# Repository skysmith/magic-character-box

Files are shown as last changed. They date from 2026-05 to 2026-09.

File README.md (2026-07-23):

# Magic Character Box

Build a magic NFC story box for kids with Raspberry Pi.

Magic Character Box is a local-first maker project where NFC-tagged toys, tokens, or figures trigger songs, stories, sound effects, and family voice messages. Put a character on top, read its NFC UID, map that UID to an audio folder, and play the matching files.

Smaller sidecar enclosure preview

The finished kid box should use:

```text
5V charger -> Raspberry Pi Zero 2 W -> MAX98357A I2S amp -> passive speaker
```

The software is intentionally testable before the hardware is finished. By default it uses a keyboard-backed mock NFC reader, so you can type `DINOSAUR`, `ROCKET`, or `DAD` and verify the app loop on a Mac/Linux machine.

## Start Here

- Quick build path: [docs/quick-build.md](docs/quick-build.md)
- Build guide: [docs/assembly.md](docs/assembly.md)
- Birthday weekend path: [docs/birthday-weekend-build.md](docs/birthday-weekend-build.md)
- Materials list: [docs/materials.md](docs/materials.md)
- Wiring and pin map: [docs/wiring.md](docs/wiring.md) and [docs/pi-zero-2w-pin-map.md](docs/pi-zero-2w-pin-map.md)
- NFC registration: [docs/rf-programming.md](docs/rf-programming.md)
- Web admin: [docs/web-admin.md](docs/web-admin.md)
- Troubleshooting: [docs/troubleshooting.md](docs/troubleshooting.md)
- v0.1 release checklist: [docs/release-checklist.md](docs/release-checklist.md)
- Known limitations: [docs/known-limitations.md](docs/known-limitations.md)
- System sounds: [docs/system-sounds.md](docs/system-sounds.md)
- Hardware profiles: [docs/hardware-profiles.md](docs/hardware-profiles.md)
- Optional transactional player-load bridge: [docs/transactional-player-load.md](docs/transactional-player-load.md)
- Printable assets: [docs/printable-assets.md](docs/printable-assets.md)
- Printable STL files: [stl/](stl/README.md)
- Parametric CAD source: [cad/](cad/README.md)

## Build It Now

For the recommended first build:

1. Buy or gather the parts in [materials.md](docs/materials.md).
2. Wire the PN532 and MAX98357A from [wiring.md](docs/wiring.md).
3. Run `./scripts/install_pi.sh` on the Pi.
4. Open the dashboard at `http://<pi-hostname-or-ip>:8080`.
5. Click `Setup scan`, scan a blank sticker, name it, and add its first sound.
6. Click `Playback`, place the character on the box, and listen.

The shortest copy-and-build version is [docs/quick-build.md](docs/quick-build.md).

## Why Build This

- Screen-free, physical interaction for kids.
- Beginner-friendly Raspberry Pi, NFC, Python, and audio practice.
- Easy to personalize with a Dad Token, Grandma Token, dinosaur facts, bedtime stories, or secret missions.
- Can also become a Story Dock / Story Album: NFC-tagged printed photos that play family memories and voice notes.
- Expandable from an ugly desk demo into a kid-usable enclosure and local parent admin page.

## Story Dock Boundary

Story Dock commercial product work lives in the private sibling `story-dock`
repo. This public repo stays focused on the local Magic Character Box build and
may keep open-source bridge pieces for local photo-story and guest-recorder
flows, but not hosted backend secrets, launch plans, supplier docs, or private
customer/product strategy.

## Current Behavior

- Reads NFC UIDs from either a mock keyboard reader or a PN532 over SPI.
- Offers an explicit `pn532-ndef` hosted mode that identifies a Story Sticker
  from either a verified legacy `https://tap.getstorydock.com/s/<token>` URL or
  a versioned `https://tap.getstorydock.com/s/<T32>/SD03-0001` URL. The suffix
  path resolves its public alias through authenticated hosted config to the
  same opaque `sdpk1_...` identity. UID is only a learned local acceleration.
- Normalizes UIDs such as `04:a1:22:9b` to `04-A1-22-9B`.
- Looks up characters in `config/characters.json`.
- Stops current playback when a different known character is scanned.
- Plays the first, shuffled, or next sequenced `.mp3` file in the mapped folder.
- Ignores repeat scans of the same tag identity for a cooldown window.
- Continues playing when a tag is removed. In the MVP, only a new known tag changes playback.
- Plays a startup chime when the service starts.
- Plays a friendly discovery cue for unknown/unregistered tags.
- Shares a tiny `config/device_state.json` file with the dashboard for the last-seen tag and recent plain-language events.

Normal maker mode hot-reloads valid `characters.json` edits and preserves its
last in-memory mapping when a rewrite is invalid. Coordinated installers may
instead opt into the local, credential-free transactional player-load bridge;
it is off by default and ordinary maker installs are unchanged. See
[docs/transactional-player-load.md](docs/transactional-player-load.md).

## Quick Start: Dev Mode

```bash
cd magic-character-box
python3 -m venv .venv
. .venv/bin/activate
pip install -r requirements.txt
python -m magic_box.app --nfc mock --dry-run-audio
```

At the prompt, type:

```text
DINOSAUR
ROCKET
DAD
q
```

Dry-run audio logs what it would do without launching `mpg123`. To hear sound, add legally usable MP3 files under:

```text
audio/dinosaur/
audio/rocket/
audio/dad/
```

Then install `mpg123` and run without `--dry-run-audio`:

```bash
python -m magic_box.app --nfc mock
```

## Pi Setup

On the Raspberry Pi:

```bash
cd /home/pi/magic-character-box
./scripts/install_pi.sh
```

The install script also runs `scripts/generate_system_sounds.sh`, which creates the startup chime, unknown-tag cue, success/error cues, and silent warmup MP3.

Then enable SPI:

```bash
sudo raspi-config
```

Choose `Interface Options` -> `SPI` -> enable, then reboot.

For the MAX98357A speaker, follow `docs/wiring.md`; the Pi service files pin playback to the direct `plughw:CARD=MAX98357A,DEV=0` ALSA path so the built-in speaker behaves consistently across cards.

For a wiring cheat sheet and reserved-pin ledger, use [docs/pi-zero-2w-pin-map.md](docs/pi-zero-2w-pin-map.md). The same reservations are available as JSON in [config/pin-reservations.json](config/pin-reservations.json).

Service deployment notes are in [docs/pi-deployment.md](docs/pi-deployment.md).

## Run With Real PN532

```bash
python -m magic_box.app --nfc pn532
```

You can also use environment variables:

```bash
MAGIC_BOX_NFC=pn532 \
MAGIC_BOX_AUDIO_BACKEND=continuous-pcm \
MAGIC_BOX_AUDIO_CMD="mpg123 -q -s --rate 48000 --stereo -e s16" \
MAGIC_BOX_AUDIO_SINK_CMD="aplay -q -D plughw:CARD=MAX98357A,DEV=0 --file-type raw --format S16_LE --rate 48000 --channels 2 --buffer-time=100000 --period-time=20000" \
python -m magic_box.app
```

Ordinary `pn532` mode keeps the public maker workflow and uses the physical tag
UID. A hosted deployment can opt in to URL identity instead:

```bash
python -m magic_box.app --nfc pn532-ndef
```

In `pn532-ndef` mode, the tag must contain exactly one canonical Story Dock
NDEF HTTPS URI record. Legacy URLs are parsed completely. New suffix URLs put
the public `SDxx-xxxx` alias in a fixed page-19 read window; the player accepts
that alias only when the active hosted config maps it to a canonical
token-derived `sdpk1_...` key. A hashed local UID binding can accelerate later
taps but is never returned or configured as identity. URLs, tokens, and raw
UIDs are not written to logs or hosted config.

## Scan A Tag

```bash
python scripts/scan_tag.py --nfc pn532
```

For a laptop/dev placeholder:

```bash
python scripts/scan_tag.py --nfc mock
```

## Test Without The Reader

Before the PN532 and stickers arrive, run the real app loop with the file-backed fake reader:

```bash
MAGIC_BOX_NFC=file python -m magic_box.app --nfc file
```

In another terminal, queue pretend tag IDs:

```bash
python scripts/fake_tag.py DINOSAUR
python scripts/fake_tag.py ROCKET
python scripts/fake_tag.py DAD
```

The app consumes one queued UID at a time from `/tmp/magic-character-box-tags.txt`. This is the easiest way to test the Pi service, config lookup, cooldown behavior, and audio switching without touching NFC hardware.

The admin UI also has a `Simulate scan` button for each character. When the app service is running with `MAGIC_BOX_NFC=file`, that button queues the same fake UID and the background app plays it as if a toy had been placed on the reader.

## Register A Character

```bash
python scripts/register_character.py --nfc pn532 --name Dinosaur --mode shuffle
```

This reads one tag UID, creates a folder such as `audio/dinosaur`, and updates `config/characters.json`.
If a folder with that name already exists, the helper appends a number, such as `audio/dinosaur-2`.
Use `--folder audio/custom-name --create-folder` only when you want to override the automatic folder name.

## Device Admin UI

Run the local web admin when you want a phone/laptop interface for the box:

```bash
python -m magic_box.admin --nfc pn532 --host 0.0.0.0 --port 8080
```

Open `http://<your-pi-hostname-or-ip>:8080` on the same network.

If the Pi is on your Tailscale tailnet, Tailscale Serve can expose the same dashboard over trusted tailnet HTTPS without creating a second admin service. For example, a Tailscale URL can look like `https://your-box.your-tailnet.ts.net/`.

The admin UI can:

- Upload audio to a character immediately after files are selected.
- Upload a family voice memo from a phone or laptop.
- Record in the browser only when the page is running from a secure origin, such as localhost or a guest-only HTTPS tunnel.
- Create an upload-only guest recording link for a remote family member.
- Register an NFC tag UID without editing JSON, creating the audio folder automatically from the character name.
- Create a photo story in one pass: scan a sticker, name the memory, and generate a phone recorder link.
- Create Story Sticker URLs for the newer Story Dock flow: preassign a phone-tap link, bind the NFC UID, record from a phone, and expose the story in `/api/dock/manifest`.
- Download QR SVG fallbacks for Story Sticker links and guest recorder links. This is the free/open-source print option for people who do not have prewritten NFC URL stickers yet.
- Serve a first mobile API for future native iPhone/App Clip work at `/api/mobile/story-stickers/<token>`.
- Point Story Sticker links at a hosted/tunneled URL with `MAGIC_BOX_PUBLIC_STORY_BASE_URL` during staging.
- Switch between setup scanning and kid playback mode from the dashboard.
- Check Wi-Fi status, scan nearby networks, and connect through the local NetworkManager controls on the Pi.
- Use the last-seen tag to teach a new character without copying a UID.
- Run a one-click box test from the hidden tools drawer.
- Download a backup zip of `config/` and `audio/`.
- Shut down the Pi cleanly from the local dashboard.
- Leave room for experimental Bluetooth speaker work without making it part of the main build.
- Show guidance for custom 3D printable figures.

Browser recordings are converted to MP3 when `ffmpeg` is installed. `scripts/install_pi.sh` installs `ffmpeg` on the Pi.

For Grandma-style remote messages, create a guest recording link from the dashboard or command line:

```bash
python scripts/create_guest_link.py --name "Dad Token" --label "Grandma birthday message" --base-url https://your-temporary-tunnel.example
```

The guest page is upload-only. For a temporary public tunnel, run the app in `--guest-only` mode on a separate local port so the tunnel cannot serve the dashboard, scan controls, file deletion, Bluetooth controls, or system mode buttons. That guest recorder is not a second dashboard; the single parent dashboard stays on `http://<pi-hostname-or-ip>:8080`.

When using the real PN532 Scan button, run the real admin service and stop the mock/dev admin service. If the Scan button is disabled and the page says browser scan is unavailable, the admin is running in mock mode.

See [docs/web-admin.md](docs/web-admin.md), [docs/rf-programming.md](docs/rf-programming.md), and [docs/3d-printable-figures.md](docs/3d-printable-figures.md).

Bluetooth controls are intentionally treated as an experimental socket for future contributors. The finished kid box defaults to the wired MAX98357A amp path because it boots predictably and does not depend on a paired accessory.

## Install Services

After copying the repo to `/home/pi/magic-character-box` and running `scripts/install_pi.sh`:

```bash
sudo cp systemd/magic-character-box.service /etc/systemd/system/
sudo systemctl daemon-reload
```

To install the web admin as a separate service:

```bash
sudo cp systemd/magic-character-box-admin.service /etc/systemd/system/
sudo systemctl daemon-reload
```

The MVP app and admin page are separate PN532 readers. Use either setup mode or kid playback mode:

```bash
# Setup mode: register tags and upload/record audio
sudo systemctl disable --now magic-character-box
sudo systemctl disable --now magic-character-box-admin-dev
sudo systemctl enable --now magic-character-box-admin

# Kid playback mode
sudo systemctl disable --now magic-character-box-admin
sudo systemctl enable --now magic-character-box
```

Watch logs with `journalctl -u magic-character-box -f` or `journalctl -u magic-character-box-admin -f`.

Adjust `WorkingDirectory`, `User`, and `ExecStart` in the service file if you install somewhere other than `/home/pi/magic-character-box`.

## Tutorial Stages

Follow [docs/tutorial-roadmap.md](docs/tutorial-roadmap.md):

1. The ugly magic demo.
2. Make it kid-usable.
3. The birthday box.
4. Parent-friendly admin.

The first printable case model is in [cad/](cad/README.md). It has rounded dice-like edges, a screw top, side speaker holes, and internal spaces for the Pi, PN532 reader, MAX98357A amp, and a small passive speaker.

The smaller current prototype enclosure is the sidecar version. It mounts the electronics beside an existing passive speaker cabinet. Ready-to-slice STL files are in [stl/](stl/README.md):

- `small-sidecar-enclosure-body.stl`
- `small-sidecar-enclosure-lid.stl`
- `nfc-character-base-flat.stl`

## Open Source And Media

This repo is licensed under Apache License 2.0. See [LICENSE](LICENSE).

The repo intentionally does not include music, stories, character art, or private voice recordings. Add your own audio locally. Good sources include family recordings, original audio, public-domain media, and Creative Commons audio with compatible terms.

See [docs/open-source-notes.md](docs/open-source-notes.md), [docs/audio-sources.md](docs/audio-sources.md), and [CONTRIBUTING.md](CONTRIBUTING.md).

## Project Screenshots And Photos

Useful open-source presentation assets are included under `docs/assets/`:

- Dashboard screenshot: [docs/assets/screenshots/software-admin-library.png](docs/assets/screenshots/software-admin-library.png)
- Bluetooth/future socket screenshot: [docs/assets/screenshots/software-bluetooth-control.png](docs/assets/screenshots/software-bluetooth-control.png)
- Pi header photo: [docs/assets/photos/pi-zero-2w-header.jpg](docs/assets/photos/pi-zero-2w-header.jpg)
- Amp wiring photo: [docs/assets/photos/max98357a-wired-to-pi.jpg](docs/assets/photos/max98357a-wired-to-pi.jpg)

Before publishing new photos, use the checklist in [docs/release-checklist.md](docs/release-checklist.md).

## Notes

- NFC UIDs are fine toy identifiers, not security credentials.
- Do not connect a passive speaker directly to the Pi. The MAX98357A drives the speaker; the Pi only powers the amp and sends I2S audio.
- Keep audio local for the birthday MVP. Streaming services can wait.

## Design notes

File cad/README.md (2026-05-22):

# Case CAD

This folder contains a first printable enclosure for the Magic Character Box.

The default model is a two-piece screw-top box. That is the recommended first print because you can open the box, move the NFC reader, fix wiring, replace the speaker, and iterate without destroying the case.

There is also a `sidecar` variant for the current prototype direction: keep an existing passive speaker as the speaker cabinet and Velcro a smaller electronics module to its side or back.

## Files

- `magic-character-box-case.scad`: parametric OpenSCAD source.
- `nfc-character-base.scad`: reusable character puck with an underside NFC sticker recess.
- `build_case.sh`: renders STL files when OpenSCAD is installed.
- `build/`: generated STL output.
- `../stl/`: small public STL set for the recommended sidecar enclosure and NFC base.

## Design

- Rounded/blunted dice-like edges.
- Removable screw top.
- Side-face speaker perforations on both left and right sides.
- Raised top target ring for NFC character placement on the standalone box.
- Underside lid tray sized for a PN532 V3-style reader on the standalone box.
- Bottom standoffs for Raspberry Pi Zero 2 W.
- Small amp pad for a MAX98357A board.
- Broad front cable window for USB power/data during prototyping.

## Sidecar Variant

The sidecar variant is for mounting the Pi/NFC/amp electronics to an existing passive speaker cabinet with hook-and-loop tape.

Differences from the standalone box:

- Slightly smaller footprint and height.
- No printed speaker grille/perforations.
- Flat rear Velcro pad.
- Two rounded vertical strap slots as a backup to adhesive Velcro. They also make the rear face look intentionally character-like.
- Shallow smile and cheek details on the rear pad.
- Small side exit for speaker wires running to the speaker terminals.
- The PN532 mounts in a shallow recessed pocket under the lid instead of a printed tray. This keeps the antenna close to the NFC tag and gives clone PN532 boards extra clearance.
- The ready-to-slice sidecar lid omits the raised NFC target ring and is exported with the flat visible face on the print bed, so it can print without support material. Mark the target area later with paint, vinyl, or a sticker.

Keep the PN532/NFC target several inches away from the speaker magnet and metal hardware when choosing the exact Velcro location.

Ready-to-slice sidecar files are copied to [`../stl/`](../stl/README.md):

- `small-sidecar-enclosure-body.stl`
- `small-sidecar-enclosure-lid.stl`
- `small-sidecar-enclosure-assembly.stl` for visual/reference use

## Hardware Assumptions

- Raspberry Pi Zero 2 W: 65 mm x 30 mm board footprint.
- PN532 V3-style NFC reader: about 42.7 mm x 40.4 mm.
- MAX98357A amp breakout: mounted with tape/zip tie on the small internal amp pad.
- Speaker: small passive speaker mounted behind either perforated side face with foam tape, hot glue, or a printed bracket in a later revision.
- Sidecar Pi standoffs: raised to 8 mm so the Pi Zero 2 W USB ports line up better with the cable access window.

Measure your exact parts before a final gift print. Clone boards can vary.

## Render STLs

```bash
cd cad
./build_case.sh
```

Or render one part:

```bash
openscad -o build/magic-character-box-body.stl -D 'part="body"' magic-character-box-case.scad
openscad -o build/magic-character-box-lid.stl -D 'part="lid"' magic-character-box-case.scad
```

Render the smaller sidecar parts:

```bash
openscad -o build/magic-character-box-sidecar-body.stl -D 'variant="sidecar"' -D 'part="body"' magic-character-box-case.scad
openscad -o build/magic-character-box-sidecar-lid.stl  -D 'variant="sidecar"' -D 'part="lid"'  magic-character-box-case.scad
```

Render only the reusable NFC figure bases:

```bash
openscad -o build/nfc-character-base-flat.stl   -D 'part="flat"'   nfc-character-base.scad
openscad -o build/nfc-character-base-peg.stl    -D 'part="peg"'    nfc-character-base.scad
openscad -o build/nfc-character-base-socket.stl -D 'part="socket"' nfc-character-base.scad
```

## Reusable Character Base

The character base is a 42 mm rounded puck sized for common 25 mm NTAG213/215/216 stickers.

- `nfc-character-base-flat.stl`: default base. Merge a figure STL onto the flat top pad.
- `nfc-character-base-peg.stl`: adds a small center peg for figures designed with a matching hole.
- `nfc-character-base-socket.stl`: adds a center socket for figures designed with a matching peg.
- `nfc-character-base-demo.stl`: quick visual reference with a simple placeholder figure.

The NFC sticker goes in the underside recess. Keep the sticker on the bottom face so it sits close to the reader in the box lid. Cover it with thin felt or tape if the figure will slide around.

Base source-of-truth dimensions:

| Feature | Value |
| --- | ---: |
| Base diameter | 42 mm |
| Main base height | 8 mm |
| Flat variant total height | 8.8 mm |
| Top landing pad | 32 mm diameter x 0.8 mm high |
| Sticker recess | 26.4 mm diameter x 0.8 mm deep |
| Intended sticker | 25 mm round NTAG213/215/216 |
| Removal notch | 7 mm diameter |
| Peg variant | 7.8 mm diameter x 3.2 mm high |
| Socket variant | 8.4 mm diameter x 3.4 mm deep |

More figure workflow notes are in [`../docs/3d-printable-figures.md`](../docs/3d-printable-figures.md).

## Print Notes

Suggested first settings:

- Material: PLA or PETG.
- Layer height: 0.2 mm.
- Walls: 3.
- Top/bottom layers: 4.
- Infill: 15-20%.
- Supports: off for the sidecar body and lid. Check your slicer preview for the standalone lid lip and PN532 tray.
- Screws: start with M2.5 or small self-tapping screws. The lid uses clearance holes and the body has pilot holes.

Print the body open-side up. The sidecar lid STL is already oriented flat-side down; print it as-is with the internal lip and PN532 recess facing upward.

For the sidecar, put adhesive Velcro on the flat rear pad. If the tape alone feels weak, pass a thin Velcro strap or zip tie through the two rounded vertical eye slots. Route the speaker wire through the small side exit.

Print the NFC character base flat-side down with supports off. The underside sticker recess is shallow enough to bridge cleanly on most printers, but check the slicer preview.

For the full public build flow, see [`../docs/assembly.md`](../docs/assembly.md).

## Assembly Order

1. Print the body and lid.
2. Test fit screws before installing electronics.
3. Mount the Pi Zero 2 W on the floor standoffs.
4. Mount the MAX98357A amp on the internal amp pad.
5. For the sidecar lid, hot-glue, foam-tape, or VHB-tape the PN532 reader into the recessed pocket, antenna facing the thin lid window. For the standalone lid, mount the PN532 reader under the lid in the tray.
6. For the standalone box, mount the speaker behind a side perforation field. For the sidecar, route speaker wires out to the speaker terminals.
7. Wire everything with the Pi powered off.
8. Run NFC/audio tests before closing the lid.

## Paused-Print Variant

A mid-print component capture is possible, but it is not the recommended first version. It makes repairs and debugging much harder, and the print bed/nozzle environment is not friendly to electronics.

If you still want a captured-electronics print later, use this screw-top model as the dimensional prototype first. Once board positions are confirmed, a later model can remove the lid seam and add a slicer pause just before the top bridge closes.

## Sources For Dimensions

- Raspberry Pi Zero 2 W mechanical drawing: https://datasheets.raspberrypi.com/rpizero2/raspberry-pi-zero-2-w-mechanical-drawing.pdf
- Raspberry Pi Zero 2 W hardware docs: https://www.raspberrypi.com/documentation/hardware/raspberry-pi-zero-2/
- PN532 V3 guide dimensions commonly list the board around 42.7 mm x 40.4 mm.

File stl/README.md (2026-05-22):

# Printable STL Files

This folder contains ready-to-slice STL files for the first public build.

The OpenSCAD source lives in [`../cad/`](../cad/README.md). If you change dimensions, regenerate these files with:

```bash
./cad/build_case.sh
```

## Smaller Sidecar Enclosure

Use these when mounting the electronics module to the side or back of an existing passive speaker cabinet:

- [`small-sidecar-enclosure-body.stl`](small-sidecar-enclosure-body.stl)
- [`small-sidecar-enclosure-lid.stl`](small-sidecar-enclosure-lid.stl)
- [`small-sidecar-enclosure-assembly.stl`](small-sidecar-enclosure-assembly.stl) for visual/reference use

Print the body open-side up. The lid STL is already oriented with its flat visible face on the print bed; print it as-is with supports off.

The sidecar lid has a recessed PN532 pocket on the inside. Hot-glue, foam-tape, or VHB-tape the reader into that pocket with the antenna facing the thin lid window.

The sidecar body has rounded rear strap slots that double as a cute face, plus shallow smile and cheek details on the rear pad. The Pi standoffs are raised so the Pi Zero 2 W USB ports line up better with the access window.

## Character Base

- [`nfc-character-base-flat.stl`](nfc-character-base-flat.stl)

This is a reusable 42 mm base with an underside recess for a common 25 mm NFC sticker. Drop or merge a custom figure model onto the flat top pad, then put the NFC sticker in the bottom recess.

Specs:

| Feature | Value |
| --- | ---: |
| Overall diameter | 42 mm |
| Total flat-base height | 8.8 mm |
| Top landing pad | 32 mm diameter |
| Sticker recess | 26.4 mm diameter x 0.8 mm deep |
| Intended sticker | 25 mm round NFC sticker |
| Recess notch | 7 mm diameter |

Print with the sticker recess on the bed and supports off. If your stickers are larger than 25 mm, edit [`../cad/nfc-character-base.scad`](../cad/nfc-character-base.scad) and regenerate the STL.

## Starting Print Settings

- Material: PLA or PETG.
- Layer height: 0.2 mm.
- Walls: 3.
- Top/bottom layers: 4.
- Infill: 15-20%.
- Supports: off for the body, lid, and character base.
- Screws: start with M2.5 x 8 mm or similar small self-tapping screws.

Measure your exact boards before a long final print. Clone PN532 and MAX98357A boards vary.

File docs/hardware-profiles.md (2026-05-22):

# Hardware Profiles

Pick one profile before buying parts. The recommended path is boring on purpose: fewer variables means more magic.

## Recommended Kid Box

Best for the finished gift.

| Part | Choice |
| --- | --- |
| Computer | Raspberry Pi Zero 2 W or Zero 2 WH |
| Reader | PN532 over SPI |
| Audio | MAX98357A I2S amp plus 4-8 ohm passive speaker |
| Power | 5V USB wall charger, 2A or better |
| Enclosure | Printed sidecar, project box, wood, or cardboard prototype |

Why this profile:

- Small.
- Runs the Python app and dashboard.
- Uses local files.
- Built-in speaker path does not depend on Bluetooth pairing.

## Simplest Desktop Prototype

Best for proving the software before the speaker box works.

| Part | Choice |
| --- | --- |
| Computer | Any Raspberry Pi with Wi-Fi/Ethernet |
| Reader | Mock/file reader first, PN532 later |
| Audio | HDMI, USB speaker, or the computer's default audio |
| Power | Normal Pi power supply |

Run:

```bash
python -m magic_box.app --nfc mock --dry-run-audio
```

Then remove `--dry-run-audio` after adding MP3s and installing `mpg123`.

## Cheapest Use-What-You-Have Pi

Best when you already own an older board.

| Board | Notes |
| --- | --- |
| Raspberry Pi Zero W / Zero WH | Works for basic playback, but slower for dashboard uploads and `ffmpeg` conversion. |
| Raspberry Pi 3A+ | Good alternate, larger than Zero. |
| Raspberry Pi 3B/3B+/4B | Easy and fast, larger enclosure and higher power draw. |

Use the same PN532 and MAX98357A wiring pattern, but verify physical pin numbers before powering up.

## Contributor Porting Targets

These are plausible but not beginner-default.

| Board | Notes |
| --- | --- |
| Radxa Zero 3W | Small, capable, Linux-based. Needs board-specific SPI/I2S setup. |
| Orange Pi Zero 2W | Cheap and small. Expect OS and GPIO/I2S differences. |
| Other Linux SBCs | Fine if they expose SPI, I2S or USB audio, and can run Python 3.10+. |

To support a new board well, contribute:

- Working install notes.
- Pin map.
- SPI setup notes.
- Audio output setup.
- Any service file changes.

## Not This Software Stack

These can inspire a different project, but they are not drop-in replacements:

- Raspberry Pi Pico W.
- ESP32.
- Seeed XIAO ESP32S3.
- Arduino-class boards.

They can read NFC and trigger audio with different hardware, but this repo assumes Linux, Python, Flask, local file storage, `mpg123`, and systemd.

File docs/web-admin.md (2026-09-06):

# Device Admin UI

The device admin UI is a local web page served by the Raspberry Pi. It is meant for parent/setup use on the home network, not for public internet exposure.

## Start It

For setup on the Pi:

```bash
python -m magic_box.admin --nfc pn532 --host 0.0.0.0 --port 8080
```

Then open:

```text
http://<your-pi-hostname-or-ip>:8080
```

There is one parent dashboard. Keep it on `http://<your-pi-hostname-or-ip>:8080` on your trusted home network. Do not expose the full dashboard to the public internet.

If the Pi is joined to your Tailscale tailnet, you can also proxy the same dashboard through Tailscale Serve:

```bash
tailscale serve --bg --yes 8080
```

That gives trusted HTTPS inside your tailnet without a separate admin service. A private Tailscale URL usually looks like:

```text
https://your-box.your-tailnet.ts.net/
```

Browser microphone recording requires a secure origin. The dashboard hides browser recording when the browser will block it. Use one of these paths:

- Upload an existing voice memo from the same character panel.
- Create a guest recorder link and open that guest-only page through a temporary HTTPS tunnel.
- Run the dashboard on `localhost` during desktop development.

For laptop/dev testing:

```bash
python -m magic_box.admin --nfc mock --host 127.0.0.1 --port 8080 --dry-run-audio
```

In mock mode, browser scanning is disabled; type the UID manually.
If the Scan button is disabled and the page says "Browser scan is unavailable here," the admin is running in mock mode, not PN532 mode.

## Recovery Wi-Fi Page

When the box is broadcasting its setup/recovery Wi-Fi network, open:

```text
http://10.42.0.1:8080/
```

That address lands on a single-purpose reconnect page instead of the full dashboard. The page asks for the home Wi-Fi network and password, then shows the next instructions before requesting the network switch. Return the phone to home Wi-Fi or cellular internet and continue from the private setup email. Returning owners can choose **Open My Story Dock**. The page does not automatically navigate away or treat a lost local connection as proof that Wi-Fi joined successfully. A rejected request restores the form for correction.

The full local dashboard stays closed on the recovery network. Integrators may
enable the explicit recovery-support profile for supervised bench work, but a
customer recovery session exposes only the reconnect page and its narrowly
scoped Wi-Fi actions.

## What It Does

- Shows registered characters.
- Uploads audio files into a character folder as soon as files are selected.
- Uploads phone voice memos for family messages.
- Shows browser recording controls only when the page is running from a secure origin, such as localhost or a guest-only HTTPS tunnel.
- Converts browser recordings to MP3 when `ffmpeg` is installed.
- Creates tokenized guest recording links for remote family voice messages.
- Creates preassigned Story Sticker URLs for the Story Dock phone-tap flow.
- Downloads QR SVG fallbacks for guest links and Story Sticker links.
- Registers NFC tag UIDs into `config/characters.json` and creates the audio folder automatically from the character name.
- Shows the last tag seen by either the dashboard or the playback service.
- Shows a small recent event log in a drawer.
- Offers a hidden `Box tools` drawer with a one-click box test, backup download, and clean shutdown.
- Tests playback through the same audio command used by the box app.
- Stops device playback by sending a local request to the main playback service.
- Sets shared software volume in `config/volume.json`.
- Shows Wi-Fi status and can scan/connect through NetworkManager on the Pi.
- Exposes an experimental Bluetooth control socket for future prototype playback work.
- Gives quick guidance for custom 3D printed figures.
- Switches between setup scanning and child playback mode from the top of the page on the Pi.

## Teach Mode

The `Teach character` section is meant to feel like teaching the box, not editing a config file:

1. `Scan a new character`.
2. `Name it`.
3. `Add its first sound`.

After a new character is saved, the dashboard opens that character's `Add first sound` panel when it has no playable audio yet.

The `Last seen tag` panel updates from `config/device_state.json`. If the kid-facing playback service notices a new/unregistered tag, the dashboard can show that UID and offer `Use this tag` without making you copy it from logs.

## Scanning Tags

The Scan button works only when the admin is running with the real PN532 backend and the playback service is not using the reader:

```bash
python -m magic_box.admin --nfc pn532 --host 0.0.0.0 --port 8080
```

On the Pi service install, use the mode controls at the top of the dashboard:

- `Setup scan`: stops `magic-character-box` so the browser Scan button can use the PN532.
- `Playback`: starts `magic-character-box` again so the kid-facing box listens for character tags.

Clicking Scan changes the button to `Scanning...` for up to 20 seconds. Hold the tag flat against the reader during that window. If no tag is found, the status text changes to a timeout message.

For the MVP, the main box app and the admin page are separate processes. Do not let both processes scan the PN532 at the same time. The top mode controls handle this for the standard service install. The manual version is:

```bash
sudo systemctl stop magic-character-box magic-character-box-admin-dev
sudo systemctl start magic-character-box-admin
```

If port `8080` is already in use, a mock admin may still be running. Stop the dev admin services and refresh the page.

## Audio Uploads

MP3 files are immediately playable by the default `mpg123` command.

In the web UI, click Upload to open the file picker. Selecting one or more files starts the upload immediately. The row shows a spinner, progress bar, and status text while the upload is running. There is no separate Save or Update button for audio files.

The admin accepts other common audio formats such as `.wav`, `.m4a`, `.ogg`, `.flac`, `.webm`, and `.mp4`. When `ffmpeg` is installed, those files are converted to MP3 on upload. If `ffmpeg` is missing, the original file is saved but marked as not playable by `mpg123` yet.

`scripts/install_pi.sh` installs both `mpg123` and `ffmpeg`.

When `ffmpeg` is available, uploaded and recorded audio is re-encoded as mono MP3 with:

- short fade-in and fade-out edges to reduce clicks
- loudness normalization so family clips and songs land closer to the same perceived volume

## Guest Recording Links

Guest links are for remote family messages. A guest link opens a single upload-only page at:

```text
/guest/<token>
```

The guest page can:

- Upload an existing phone voice memo or audio file.
- Record from the browser microphone when opened from a secure HTTPS link.
- Save the message into one selected character folder.

The guest page cannot delete files, scan NFC tags, change playback mode, pair Bluetooth devices, or see the admin dashboard.

Create links from the dashboard under `Guest links`, or from SSH:

```bash
python scripts/create_guest_link.py \
  --name "Dad Token" \
  --label "Grandma birthday message" \
  --days 14 \
  --base-url https://your-temporary-tunnel.example
```

Guest link metadata is stored in:

```text
config/guest_links.json
```

For someone outside your home network, run a guest-only local server and put a temporary HTTPS tunnel in front of that, not the full admin dashboard.

Terminal 1:

```bash
python -m magic_box.admin \
  --guest-only \
  --config config/characters.json \
  --host 127.0.0.1 \
  --port 8090
```

Terminal 2: [Cloudflare documents Quick Tunnels](https://developers.cloudflare.com/cloudflare-one/networks/connectors/cloudflare-tunnel/do-more-with-tunnels/trycloudflare/) for development/testing with:

```bash
cloudflared tunnel --url http://localhost:8090
```

That command prints a random `trycloudflare.com` URL.

Terminal 3:

```bash
python scripts/create_guest_link.py \
  --name "Dad Token" \
  --label "Grandma birthday message" \
  --days 14 \
  --base-url https://random-words.trycloudflare.com
```

Send the printed guest URL. Stop the guest-only server and tunnel after the recording is received.

The dashboard's `Guest links` form has an optional `Guest access` field. The dashboard fills it with the best secure origin it can see:

- If opened through Tailscale HTTPS, it uses the Tailscale dashboard origin.
- If `MAGIC_BOX_PREFERRED_GUEST_BASE_URL` is set, it uses that as the default secure origin.
- If you paste a public guest-only tunnel URL, the guest link uses that tunnel instead.

The guest link list labels each link as private Tailscale HTTPS, public/secure, or local Wi-Fi so you know who can use it.

Each guest link row also has a `QR SVG` button. Use it when a printed card is easier than sending a URL. The QR opens the same upload-only guest recorder link; it does not expose the admin dashboard.

## Story Sticker Links

`Story stickers` is the first version of the newer Story Dock software direction.

It creates a stable phone URL:

```text
/story/<token>
```

That URL is what a future factory-encoded NFC sticker/card would open on a phone. In the open-source Pi build, you can use it now by:

1. Creating a Story Sticker link in the dashboard.
2. Optionally binding the real sticker UID immediately.
3. Opening the generated `/story/<token>` link on a phone, or downloading its `QR SVG` fallback and printing it on a backing card or setup sheet.
4. Naming the memory and recording or uploading a voice memo.
5. Tapping the physical sticker/photo on the dock after the UID is bound.

The QR fallback is intentionally a free/open-source bridge. It is useful before you have prewritten NFC URL stickers, or when a phone case/device does not read NFC reliably. Keep QR codes on backing cards, setup sheets, sleeves, or support material; the main Story Sticker face can stay decorative.

The phone URL can save a recording before the UID is known, but the current Pi playback loop still needs the UID-to-folder mapping before the dock can play it. Bind the UID from the dashboard once the reader can scan the sticker.

Story Sticker data is stored in:

```text
config/story_stickers.json
```

That file contains private URL tokens and should not be committed.

The local dock sync contract is:

```text
GET /api/dock/manifest
```

It returns Story Dock manifest JSON with stories, UIDs, Story Sticker tokens, playback modes, playable file URLs, and unbound sticker records. The current Pi app does not need this endpoint for local playback yet; it exists so the product direction has a clean software seam for a future dock service or supplier firmware.

The local mobile-app contract starts with:

```text
GET /api/mobile/story-stickers/<token>
POST /api/mobile/story-stickers/<token>/recordings
GET /api/mobile/story-stickers/<token>/recordings/<filename>
```

The first endpoint returns JSON story status, saved recording metadata, and upload links. The second accepts multipart audio and always returns JSON, which is the first practical target for a polished iPhone app or App Clip. The recording endpoint serves saved audio for preview/debug.

For hosted Story Dock staging, set:

```bash
MAGIC_BOX_PUBLIC_STORY_BASE_URL=https://tap.getstorydock.com
```

That makes dashboard-generated Story Sticker links and mobile API links point at the hosted or tunneled story base instead of the local dashboard host.

The local Pi stores Story Sticker tokens in `config/story_stickers.json` because
it is a self-hosted prototype. Hosted Story Dock backend work belongs in the
private `story-dock` repo and should use hashed, revocable tokens plus private
audio storage instead of raw sticker tokens or user passwords.

## Stop Audio

The `Stop audio` button stops any clip launched from the dashboard and also writes a one-time request to `config/control.json` for the main `magic-character-box` playback service.

If a character is still sitting on the reader, the service stops the current clip and keeps ignoring that same tag until it is lifted and placed again. That keeps the button from immediately retriggering the same song.

## Box Tools

The `Box tools` drawer is intentionally tucked under `Device details` so the day-to-day dashboard stays simple.

- `Test box` plays the startup chime, checks NFC scan readiness, reports audio command status, checks playback/setup mode, and shows free storage.
- `Download backup` returns a zip with the character config, guest links, volume/control/state files when present, and everything under `audio/`.
- `Shutdown box` asks the Pi to shut down cleanly with `sudo -n shutdown -h now`.

The shutdown command can be overridden for unusual installs:

```bash
MAGIC_BOX_SHUTDOWN_COMMAND="sudo -n shutdown -h now"
```

Recent events are stored in:

```text
config/device_state.json
```

That file is runtime state, not a hand-edited config. It is useful for troubleshooting and for the `Last seen tag` panel.

## Volume

The MAX98357A I2S amp usually does not expose a hardware mixer to `amixer`. On the founder Pi setup, the `+` and `-` buttons save a shared volume percentage in `config/volume.json` and apply it to `mpg123` software volume on the direct ALSA `plughw` speaker path.

The service files set `MAGIC_BOX_DEFAULT_VOLUME=80` and `MAGIC_BOX_MAX_OUTPUT_VOLUME=100`, so the default is easy to hear and 100% is true full-scale output. If a particular MAX98357A, speaker, power supply, or wiring path crackles at Loud, lower `MAGIC_BOX_MAX_OUTPUT_VOLUME` and restart the services rather than masking a hardware fault in the customer-facing scale.

If you intentionally override playback to Pulse/PipeWire for Bluetooth experiments, the app uses `wpctl` when available and falls back to per-player software volume otherwise.

## Wi-Fi Controls

The dashboard includes a local Wi-Fi panel when the Pi has NetworkManager's
`nmcli` command. It shows whether Wi-Fi is on, the current connection name,
and the Wi-Fi device name. Use `Scan` to list nearby networks, choose one,
enter the password locally, and connect.

The dashboard does not store or display Wi-Fi passwords after submit. Keep the
full admin page on a trusted local network or trusted Tailscale HTTPS, because
it still has maintenance controls such as shutdown, backups, scanning, and
network changes.

When the privileged helper is installed, both home-network connects and Setup
Wi-Fi password changes use bounded JSON on standard input. Passwords never
appear in the helper or `sudo` command arguments. NetworkManager receives a
home-network password through its standard-input prompt, and a changed Setup
Wi-Fi password is applied from the root-only recovery file when the next setup
session starts.

When an integrator supplies the privileged recovery helper and explicitly sets
`MAGIC_BOX_RECOVERY_PASSWORD_EDITABLE=1`, the reconnect page and full local
dashboard also offer **Change Story Dock Setup Wi-Fi password**. The form
requires an 8–63 character value and confirmation, never echoes the value in
the API response, and updates the password used the next time the setup hotspot
starts. It does not change the selected home Wi-Fi password.

## Experimental Bluetooth Socket

The Pi Zero 2 W can play to Bluetooth speakers, but Bluetooth is not part of the recommended main build. Treat it as an experimental socket for contributors and prototypes. The finished kid box should keep the MAX98357A plus passive speaker as the reliable built-in path.

The admin page includes a deliberately secondary Bluetooth panel with:

- Adapter status and current default audio output.
- Power on/off.
- Scan for nearby devices.
- Pair, connect, disconnect, and `Use for audio` buttons.

The panel shells out to `bluetoothctl` for Bluetooth actions. `Use for audio` also tries to make the matching `bluez_output` Pulse/PipeWire sink the default output using `pactl`. The Pi services default to the wired MAX98357A speaker:

```text
MAGIC_BOX_AUDIO_BACKEND=continuous-pcm
MAGIC_BOX_AUDIO_CMD=mpg123 -q -s --rate 48000 --stereo -e s16
MAGIC_BOX_AUDIO_SINK_CMD=aplay -q -D plughw:CARD=MAX98357A,DEV=0 --file-type raw --format S16_LE --rate 48000 --channels 2 --buffer-time=100000 --period-time=20000
```

That means Bluetooth speaker output is not part of the default finished-box path. If you want character audio to follow the Pi's default Pulse/PipeWire sink for a prototype, explicitly switch the player backend to `subprocess`, set its audio command to `mpg123 -q -o pulse`, and restart the services after selecting the Bluetooth sink. Do not point the `continuous-pcm` sink at PipeWire; that backend intentionally requires one direct fixed-format ALSA owner.

Install support tools on the Pi if they are missing:

```bash
sudo apt install -y bluez pulseaudio-utils
sudo systemctl enable --now bluetooth
```

If you are intentionally experimenting with Bluetooth, open the admin UI, put the speaker in pairing mode, and use:

1. `Scan for speakers`.
2. `Pair` if the speaker is new.
3. `Use for audio`.
4. Test playback from any character row.

If the speaker connects but audio still comes out of the wired speaker, refresh the Bluetooth panel and check `Default output`. You can also inspect sinks from SSH:

```bash
pactl list short sinks
wpctl status
```

For the tutorial and birthday MVP, skip this section. Wired audio is simpler to explain, easier to enclose, and more predictable for a child-facing object.

## Reducing Speaker Pops

The admin page prepares newly uploaded or recorded audio with short fades and loudness normalization so clips do not begin or end with hard waveform edges and do not vary wildly in volume.

For hardware boot/start pops, wire the MAX98357A `SD` shutdown pin to `GPIO16 / physical pin 36` instead of 3.3V, then enable the boot-time low setting described in [wiring.md](wiring.md). The app uses that pin as a boot mute and then leaves the amp enabled between clips, because waking the amp for every clip can create its own pop.

If clip starts still pop, verify the founder audio path before changing hardware:

```bash
MAGIC_BOX_AUDIO_BACKEND=continuous-pcm \
MAGIC_BOX_MAX_OUTPUT_VOLUME=100 \
MAGIC_BOX_AMP_MUTE_BETWEEN_TRACKS=0 \
MAGIC_BOX_AUDIO_CMD="mpg123 -q -s --rate 48000 --stereo -e s16" \
MAGIC_BOX_AUDIO_SINK_CMD="aplay -q -D plughw:CARD=MAX98357A,DEV=0 --file-type raw --format S16_LE --rate 48000 --channels 2 --buffer-time=100000 --period-time=20000" \
python -m magic_box.app --nfc pn532
```

The main playback service uses one long-lived direct ALSA sink and continuously
feeds it silence or decoded clip PCM. It primes that stream before enabling the
amp and keeps the amp enabled between clips. It does not start
`magic-character-box-audio-keeper.service`; the older PipeWire/`dmix` keeper
setup is historical and should not be enabled. Install `alsa-utils` so `aplay`
is available.

## Voice Recording

Browser recording uses the browser's microphone APIs. Most browsers produce WebM, Ogg, or MP4 audio, not MP3. The Pi converts that recording to MP3 with `ffmpeg` so the regular box app can play it.

If recording fails, check:

- The browser has microphone permission.
- The page is loaded from `localhost`, `127.0.0.1`, or a guest-only HTTPS tunnel.
- `ffmpeg` is installed on the Pi.
- The target character has a writable audio folder.

## Service Install

The repo includes a separate systemd service:

```bash
sudo cp systemd/magic-character-box-admin.service /etc/systemd/system/
sudo systemctl daemon-reload
sudo systemctl enable magic-character-box-admin
sudo systemctl start magic-character-box-admin
journalctl -u magic-character-box-admin -f
```

## Running Beside The Main Box App

The MVP app and admin UI are separate processes. Avoid having both processes scan the PN532 at the same time. During setup, the simplest flow is:

1. Open the dashboard.
2. Click `Setup scan`.
3. Register tags and upload or record audio.
4. Click `Playback`.

Manual equivalent:

```bash
sudo systemctl stop magic-character-box magic-character-box-admin-dev
sudo systemctl start magic-character-box-admin
```

Register tags, upload/record audio, then restart the main box app:

```bash
sudo systemctl stop magic-character-box-admin
sudo systemctl start magic-character-box
```

Later, the project can merge playback, scanning, and admin into one long-running service.

## Security

This admin UI has no login and includes maintenance actions such as backup download and Pi shutdown. Keep it on a trusted home network. Do not expose it to the public internet.

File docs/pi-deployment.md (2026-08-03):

# Pi Service Deployment

Use this after the manual tests in [assembly.md](assembly.md) pass.

These instructions assume the project has been copied to:

```text
/home/pi/magic-character-box
```

If you install somewhere else, update the `WorkingDirectory` and `ExecStart` paths in the systemd unit files.

## Install Dependencies

On the Pi:

```bash
cd /home/pi/magic-character-box
./scripts/install_pi.sh
```

Enable SPI for the PN532 reader:

```bash
sudo raspi-config
```

Choose `Interface Options` -> `SPI` -> enable, then reboot.

## Boot-Time Hardware Readiness

The player services run as `pi` with the `audio`, `gpio`, and `spi` groups.
Before Python initializes the PN532 or amp GPIO, an `ExecStartPre` check waits
up to 60 seconds for `/dev/gpiomem` and `/dev/spidev0.0` to become readable and
writable by that unprivileged process. This covers slow udev permission setup
without running the player as root. A timeout fails the start cleanly, and the
existing systemd restart policy remains the fallback.

After copying a player service, verify the same access contract manually with:

```bash
sudo -u pi /home/pi/magic-character-box/.venv/bin/python \
  -m magic_box.hardware_ready --timeout 0
```

If it fails, confirm `id -nG pi` includes `audio`, `gpio`, and `spi`, then use
[troubleshooting.md](troubleshooting.md#box-does-not-start-after-reboot).

## Audio Notes

For the MAX98357A I2S amp, configure Raspberry Pi OS to route audio to the I2S device. A typical `/boot/firmware/config.txt` setup is:

```text
dtparam=i2s=on
dtoverlay=max98357a,no-sdmode
```

If you wire the MAX98357A `SD` shutdown pin to `GPIO16 / physical pin 36`, also add:

```text
gpio=16=op,dl
```

That keeps the amp muted early in boot. See [wiring.md](wiring.md) for the full anti-pop explanation.

The included service files default to the built-in MAX98357A ALSA output through the direct `plughw` path that has been the cleanest on the founder docks:

```text
MAGIC_BOX_AUDIO_BACKEND=continuous-pcm
MAGIC_BOX_DEFAULT_VOLUME=80
MAGIC_BOX_MAX_OUTPUT_VOLUME=100
MAGIC_BOX_AUDIO_CMD=mpg123 -q -s --rate 48000 --stereo -e s16
MAGIC_BOX_AUDIO_SINK_CMD=aplay -q -D plughw:CARD=MAX98357A,DEV=0 --file-type raw --format S16_LE --rate 48000 --channels 2 --buffer-time=100000 --period-time=20000
```

Main playback keeps one direct `aplay` ALSA sink open and continuously feeds it fixed-format PCM. Idle time is zero PCM, while `mpg123 -s` decodes an active clip into that same stream. The sink receives 200 ms of silence before the amp is enabled, and idle silence is not reported as audible playback. Story paths are passed to the decoder through inherited file descriptors rather than exposed in its command line. On service stop, systemd signals the Python process first so it can cancel playback, mute the amp, terminate and reap the sink, and then release the GPIO. Volume buttons use the decoder's software volume, with `MAGIC_BOX_MAX_OUTPUT_VOLUME` acting as a small-speaker output ceiling. Install `alsa-utils` as well as `mpg123`; `aplay` is a required runtime dependency. The old PipeWire/`dmix` keeper path remains retired because it adds a second client and previously caused distortion or silence.

Bluetooth speaker support is an experimental socket, not part of the recommended deployment path. The panel uses `bluetoothctl` for pairing and `pactl` to select a matching `bluez_output` sink when possible, but the default service files stay on the wired MAX98357A speaker. Install the optional tools only if you are intentionally experimenting:

```bash
sudo apt install -y bluez pulseaudio-utils
sudo systemctl enable --now bluetooth
```

The finished kid box should use the MAX98357A speaker path as the default built-in output.

## Install The Main Box Service

Install this for kid/playback mode.

```bash
cd /home/pi/magic-character-box
sudo cp systemd/magic-character-box.service /etc/systemd/system/
sudo systemctl daemon-reload
```

Watch logs:

```bash
journalctl -u magic-character-box -f
```

## Install The Admin UI

Install this for setup mode: registering tags, uploading audio, recording messages, and testing playback from a phone or laptop.

```bash
cd /home/pi/magic-character-box
sudo cp systemd/magic-character-box-admin.service /etc/systemd/system/
sudo systemctl daemon-reload
```

Open the admin page on the same trusted network:

```text
http://<pi-hostname-or-ip>:8080
```

There is one parent dashboard. The admin page has no login, so keep it on the trusted local network and do not expose it to the public internet.

For the MVP, the main box app and real PN532 admin should not scan the reader at the same time. The commands above install the services; use one of these modes to decide what is actually running:

The admin dashboard includes top-level mode buttons for the standard service install:

- `Setup scan` stops `magic-character-box` and frees the PN532 for the browser Scan button.
- `Playback` starts `magic-character-box` again for normal child-facing playback.

Manual equivalent:

```bash
# Setup mode: real browser Scan button
sudo systemctl disable --now magic-character-box
sudo systemctl disable --now magic-character-box-admin-dev
sudo systemctl enable --now magic-character-box-admin

# Kid playback mode
sudo systemctl disable --now magic-character-box-admin
sudo systemctl enable --now magic-character-box
```

If the browser Scan button is disabled and the page says browser scan is unavailable, the mock/dev admin is running. Stop `magic-character-box-admin-dev` and start `magic-character-box-admin`.

## Temporary Remote Recording Links

For a remote family member, do not expose the full admin dashboard as the thing you send around. Create a guest recording link instead. It is tokenized, upload-only, and saves into one selected character.

Run a guest-only server on a separate local port:

```bash
cd /home/pi/magic-character-box
.venv/bin/python -m magic_box.admin \
  --guest-only \
  --config /home/pi/magic-character-box/config/characters.json \
  --host 127.0.0.1 \
  --port 8090
```

In another terminal, start the temporary tunnel:

```bash
cloudflared tunnel --url http://localhost:8090
```

Then create the link from SSH using the generated tunnel origin:

```bash
cd /home/pi/magic-character-box
.venv/bin/python scripts/create_guest_link.py \
  --name "Dad Token" \
  --label "Grandma birthday message" \
  --days 14 \
  --base-url https://random-words.trycloudflare.com
```

The [Cloudflare Quick Tunnel](https://developers.cloudflare.com/cloudflare-one/networks/connectors/cloudflare-tunnel/do-more-with-tunnels/trycloudflare/) points at the guest-only service, not the full dashboard:

```bash
cloudflared tunnel --url http://localhost:8090
```

Send only the guest recorder URL, and stop `cloudflared` plus the guest-only server after the recording is received. Quick tunnels are for short-lived testing and sharing, not permanent public hosting.

The parent dashboard also has an optional `Guest access` field when creating a guest link. It defaults to the current HTTPS dashboard origin or to `MAGIC_BOX_PREFERRED_GUEST_BASE_URL` when that environment variable is set. Paste a temporary public tunnel origin there only when you want a non-Tailscale guest to use the link.

## Fake-Tag Dev Services

If you want to test the service path before wiring NFC, use the fake-tag service:

```bash
sudo cp systemd/magic-character-box-dev.service /etc/systemd/system/
sudo cp systemd/magic-character-box-admin-dev.service /etc/systemd/system/
sudo systemctl daemon-reload
sudo systemctl enable --now magic-character-box-dev
sudo systemctl enable --now magic-character-box-admin-dev
```

The dev admin uses `--nfc mock`, so its browser Scan button is disabled. It is for fake UID and simulate-scan testing only. Do not leave the dev admin enabled once the PN532 is installed, because it can occupy port `8080` and make the real admin look broken.

Queue a fake scan:

```bash
cd /home/pi/magic-character-box
.venv/bin/python scripts/fake_tag.py DINOSAUR
.venv/bin/python scripts/fake_tag.py ROCKET
.venv/bin/python scripts/fake_tag.py DAD
```

The dev service consumes one fake UID per line from:

```text
/tmp/magic-character-box-tags.txt
```

When the PN532 is wired and working, stop the dev services and start the real services:

```bash
sudo systemctl disable --now magic-character-box-dev
sudo systemctl disable --now magic-character-box-admin-dev
sudo systemctl enable --now magic-character-box-admin
```

After registration is done, switch back to kid playback mode:

```bash
sudo systemctl disable --now magic-character-box-admin
sudo systemctl enable --now magic-character-box
```

## Smoke Tests

Mock app loop:

```bash
cd /home/pi/magic-character-box
. .venv/bin/activate
printf "DINOSAUR\nROCKET\nDAD\nq\n" | python -m magic_box.app --nfc mock --dry-run-audio
```

PN532 scan:

```bash
python scripts/scan_tag.py --nfc pn532
```

Real app with dry-run audio:

```bash
python -m magic_box.app --nfc pn532 --dry-run-audio
```

Real app with audio:

```bash
python -m magic_box.app --nfc pn532
```

## Security Checklist

- Change the Pi password if password login is enabled.
- Prefer SSH keys.
- Keep the admin UI on a trusted local network.
- Remember the dashboard includes backup download and clean shutdown controls.
- Do not commit real Wi-Fi credentials, SSH keys, private recordings, or local `.env` files.

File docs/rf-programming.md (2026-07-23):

# NFC / RF Programming Tool

The admin UI includes an "RF program tool" for registering characters.

In this project, programming does **not** mean writing data to the NFC tag. The MVP only reads the tag UID and stores that UID in `config/characters.json`.

That is intentional:

- It works with cheap blank NFC stickers and fobs.
- It avoids tag-writing mistakes.
- The box can be reset by editing one JSON file.
- The tag contains no private data.

## Mental Model

```text
NFC tag UID -> config/characters.json -> audio folder -> MP3 playback
```

Example:

```json
{
  "04-A1-22-9B": {
    "name": "Dinosaur",
    "folder": "audio/dinosaur",
    "mode": "shuffle"
  }
}
```

## Register A Tag In The Web UI

1. Start the admin UI:

   ```bash
   python -m magic_box.admin --nfc pn532 --host 0.0.0.0 --port 8080
   ```

2. Open `http://<pi-ip-address>:8080`.
3. Go to "Add tag".
4. Place the tag or character on the PN532 reader.
5. Tap "Scan". The button should change to `Scanning...`; hold the tag flat on the reader until a UID appears or the scan times out.
6. Enter a character name, such as `Dinosaur`.
7. Pick a mode:

   - `first`: always play the first MP3 in the folder.
   - `shuffle`: pick a random MP3.
   - `sequence`: advance through files in filename order.

8. Tap "Save character".
9. Upload or record audio for that character. Audio uploads begin automatically after files are selected.

The web UI creates the audio folder automatically from the character name. For duplicate names, it appends a number, such as `audio/dinosaur-2`.

## Register A Tag From The Terminal

```bash
python scripts/register_character.py --nfc pn532 --name Dinosaur --mode shuffle
```

The terminal helper uses the same automatic folder naming as the web UI.

## Manual / Mock UIDs

For development, use simple fake UIDs:

```text
DINOSAUR
ROCKET
DAD
```

In web admin mock mode, type the UID manually. Browser scan is disabled because the mock reader reads from terminal stdin.
If the browser Scan button is disabled, check that `magic-character-box-admin` is running and `magic-character-box-admin-dev` is stopped.

## When To Write Data To Tags

Do not write data to tags for the MVP.

Possible future reasons to write tags:

- Cross-box portability.
- Character metadata stored on the figure.
- Pairing tags with a mobile app.
- Story Dock phone-tap flow, where a commercial Story Sticker has a prewritten
  versioned Story Dock URL.

If that becomes necessary, add a separate `write_tag.py` tool with a dry-run mode and clear warnings. Keep UID-based registration as the default because it is simpler and harder to break.

## Story Dock URL Tags

For the commercial Story Dock direction, the sticker/card carries an NDEF URL
that both the phone and a hosted-mode dock can use:

- The phone opens the NDEF URL for recording.
- A dock started with `--nfc pn532-ndef` either verifies a complete legacy URL
  or reads the public suffix of a Luis-suffix URL from absolute page 19. The
  suffix must resolve through authenticated hosted config to an opaque
  `sdpk1_...` playback key.

The open-source dashboard's `Story stickers` tool remains a separate local
maker flow. It creates a `/story/<token>` link and stores it in
`config/story_stickers.json`; that local route is intentionally not accepted by
the strict hosted reader.

The open-source dashboard can also generate a QR SVG for that same `/story/<token>` URL. That is the free fallback path: print the QR on a backing card, photo sleeve, prompt card, or setup sheet while still using the PN532/NFC UID for dock playback when available. NFC remains the preferred magic interaction, but QR lets a phone open the same recording page without writing an NFC URL tag.

Ordinary `--nfc pn532` maker mode is unchanged and still uses the physical UID.
Hosted `pn532-ndef` mode only accepts a single canonical NDEF URI record:
legacy `https://tap.getstorydock.com/s/<token>` or versioned
`https://tap.getstorydock.com/s/<T32>/<SDxx-xxxx>`. It never treats UID, the
suffix, four digits, or a filename as identity, and it never logs the URL,
token, or raw UID. A learned hashed UID cache may skip later RF reads only
after URL or active-alias verification and is invalidated when its playback key
is no longer configured.

For a factory-encoded tag batch, the supplier may still return a manufacturing
manifest for QA and traceability:

```text
printed Sticker ID -> exact encoded URL -> optional NFC UID diagnostic
```

The runtime playback identity remains the token-derived hosted playback key;
the suffix only lets the dock reach that key with one reliable short read. The
phone recording flow and dock playback flow meet without asking a normal user
to write NFC tags or manually bind a UID at home.

## Troubleshooting

- If scan times out, check PN532 power, SPI wiring, and board switch/jumper mode.
- If the Pi cannot initialize PN532, make sure SPI is enabled with `sudo raspi-config`, then reboot.
- If tags scan intermittently, move metal away from the reader and keep the tag close to the marked top spot.
- If the Scan button is disabled, the admin page is probably running with the mock backend. Stop `magic-character-box-admin-dev` and start `magic-character-box-admin`.
- If two services are using the reader, stop one of them before scanning. During tag setup, stop `magic-character-box` and run `magic-character-box-admin`; during kid playback, stop the admin and run `magic-character-box`.

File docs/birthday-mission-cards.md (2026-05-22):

# Birthday Mission Cards

## Your Magic Character Box

These characters are empty right now.
You get to choose what powers they have.
Place one on top of the box.
The box will learn who it is.
Then we will teach it what to play.

## Mission 1: Wake The Box

Turn it on and hear the startup sound.

## Mission 2: Teach A Character

Scan a new character, name it, and add its first sound.

## Mission 3: Make A Secret Dad Token

Record a special message.

## Printable Copy

See [printable-assets.md](printable-assets.md) for label and card text you can print or paste into a document.

## Mission 4: Build The Real Case

Decorate the box and make it yours.

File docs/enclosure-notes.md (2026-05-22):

# Enclosure Notes

Start ugly and working.

The first printable case model lives in [`cad/`](../cad/README.md). It is a screw-top rounded box with side speaker holes, an NFC target ring, Pi standoffs, a MAX98357A amp pad, and a PN532 tray under the lid.

## Prototype Box

- Cardboard, wood, or a project box is enough.
- Mark a clear "place character here" circle over the NFC reader.
- Keep USB power reachable.
- Do not expose loose battery wiring.
- Avoid metal near the reader.

## Later Box

- Speaker grille.
- Chunky play/pause button.
- Better cable management.
- Optional handle.
- Adult-access panel for the Pi and SD card.

## Paused Print Option

A paused-print enclosure that traps components inside is possible later, but the screw-top case should come first. The NFC reader, amp, speaker, and Pi will probably need adjustment after the first test fit.

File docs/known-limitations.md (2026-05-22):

# Known Limitations

This project is intentionally small and local-first. These limits are part of the v0.1 design.

## Local Network Only

The admin dashboard has no login. Keep it on a trusted home network. Do not expose the full dashboard to the public internet.

For remote family voice messages, use a temporary guest-only recorder link as described in [web-admin.md](web-admin.md#guest-recording-links).

## Raspberry Pi Linux Stack

This repo assumes:

- Linux
- Python
- Flask
- local file storage
- `mpg123`
- `ffmpeg`
- systemd services

Raspberry Pi Pico W, ESP32, Seeed XIAO, and Arduino-class boards are not drop-in replacements. They could inspire a smaller firmware-only fork, but they cannot run this dashboard/software stack as-is.

## No Streaming Music Included

The project plays local audio files. It does not include Spotify, Apple Music, commercial radio, or copyrighted songs.

Builders should add family recordings, original audio, public-domain audio, Creative Commons audio with compatible terms, or legally usable personal files.

## Bluetooth Is Experimental

The dashboard includes an experimental Bluetooth output panel for contributors. The recommended kid box uses the wired MAX98357A amp and passive speaker because it boots predictably and does not depend on pairing.

Bluetooth receiver mode, where a phone streams into the box like a Bluetooth speaker, is a future roadmap item.

## No Tag Writing In The MVP

The box maps NFC tag UIDs to local folders. It does not write data onto NFC stickers.

That is simpler and harder to break. If tag writing is added later, it should be a separate advanced tool.

## Not A Finished Toy Product

This is an educational maker project. A child-facing build still needs adult judgment:

- Enclose electronics.
- Strain-relieve wires.
- Avoid loose LiPo batteries.
- Avoid sharp edges.
- Keep small removable parts appropriate for the child's age.

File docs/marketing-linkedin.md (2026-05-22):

# LinkedIn Post Draft

## Simple Post

I’ve been building a tiny Toniebox-style music and story box as an open-source Raspberry Pi project.

The idea is simple: put an NFC-tagged character or token on top of the box, and it plays that character’s songs, stories, sound effects, or family voice messages.

The fun part is that it is not just a speaker. It can become a Dad token, Grandma story token, dinosaur facts token, bedtime token, birthday token, or whatever a kid invents next.

Under the hood:

- Raspberry Pi Zero 2 W
- PN532 NFC reader
- MAX98357A amp and passive speaker
- Python playback service
- Local web admin for recording messages, uploading audio, registering tags, and testing playback
- 3D printable NFC figure bases

I’m turning it into an Apache-2.0 open-source tutorial so other parents, makerspaces, and STEM families can build their own version.

The goal is not a polished product. The goal is a magical little physical interface that a kid can understand immediately: choose a character, place it on the box, and the box comes alive.

Repo/tutorial coming together here: [add repo link]

#RaspberryPi #OpenSource #Python #NFC #MakerProject #STEM #3DPrinting

## Image Order

1. Software admin screenshot showing characters and audio upload/record controls.
2. Bluetooth/output screenshot showing device controls.
3. Finished or in-progress physical box photo.
4. Printed NFC base or figure token photo.

## Alt Text

- Screenshot of the Magic Character Box local admin page showing character rows, MP3 counts, play buttons, and controls to upload or record audio.
- Screenshot of the Magic Character Box Bluetooth speaker panel showing adapter status, default audio output, and pair/connect controls.
- Photo of the Raspberry Pi-based character audio box prototype with NFC reader, amp, and speaker wiring.
- Photo of a 3D printed NFC character base designed to hold a small NFC sticker.

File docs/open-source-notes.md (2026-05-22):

# Open Source Notes

Magic Character Box is an educational maker project: a beginner-friendly Raspberry Pi box where NFC-tagged toys trigger songs, stories, sounds, and family voice messages.

## Positioning

Use this public framing:

> Build a magic NFC story box for kids with Raspberry Pi.

## License

The software and documentation are licensed under the Apache License 2.0. See `LICENSE`.

Media files are not included. Builders should add their own legally usable audio:

- Family recordings.
- Self-made music or sound effects.
- Public-domain recordings.
- Creative Commons audio with compatible terms and proper attribution.
- Legally owned personal files for private use, where allowed.

## Repo Hygiene

- Keep sample config generic.
- Keep committed audio folders empty except for README files and `.gitkeep`.
- Do not commit private family recordings.
- Do not commit runtime files such as `config/device_state.json`, `config/guest_links.json`, `config/volume.json`, or backup zip files.
- Do not commit API keys, Wi-Fi credentials, SSH keys, or `.env` files.
- Prefer clear diagrams, electronics closeups, and build photos.
- Strip image metadata before committing photos.
- Avoid photos that show children, home addresses, mail, Wi-Fi labels, serial numbers, or private family details.
- For custom figure docs, link to tool documentation rather than redistributing generated model files you do not have rights to share.

## Public Assets

It is okay to include:

- Generated STL files for the printable enclosure and NFC bases.
- CAD source files used to generate those STLs.
- Bench photos of the Pi, amp, NFC reader, and wiring.
- Diagrams, pin maps, and screenshots of the local admin UI with fake UIDs.

Do not include:

- Media you do not have rights to publish.
- Real family voice messages.
- Real private NFC UID mappings unless the builder intentionally wants to publish them.
- Local IP addresses, hostnames tied to a private network, or SSH details.

Run through [release-checklist.md](release-checklist.md) before publishing a tag or sharing a polished build post.

## Tutorial Voice

Keep the docs friendly, concrete, and build-first. The best first impression is not a perfect enclosure; it is the moment a character touches the box and the right sound plays.

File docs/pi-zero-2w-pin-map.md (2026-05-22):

# Raspberry Pi Zero 2 W Pin Map

Use this while wiring the Magic Character Box.

Power the Pi off before moving jumper wires.

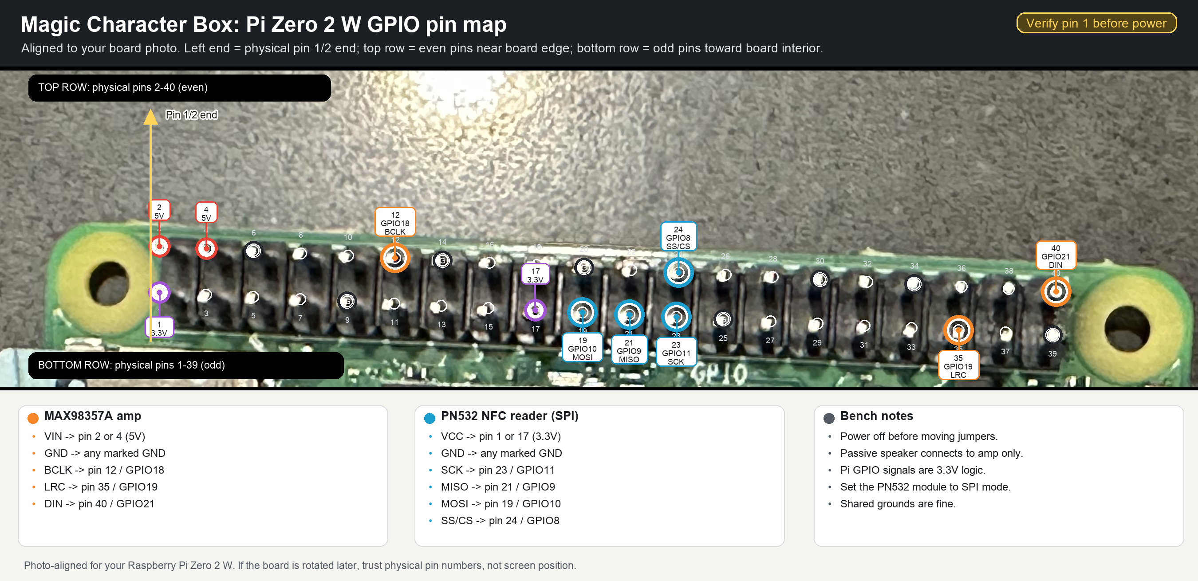
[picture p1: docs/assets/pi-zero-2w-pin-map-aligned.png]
Photo-aligned Pi Zero 2 W GPIO pin map


## Orientation

Raspberry Pi uses **physical pin numbers** and **BCM GPIO numbers**. They are not the same.

- Physical pins are the 1-40 header positions.
- BCM GPIO numbers are names like `GPIO18`, `GPIO10`, and `GPIO21`.
- Pin 1 is at the end of the GPIO header closest to the microSD card on the Pi Zero family.
- If you are unsure, find the square/silkscreen-marked pin 1 pad, or run `pinout` on Raspberry Pi OS.

## Project Wiring Summary

These pins are reserved for the first public build:

- `MAX98357A` I2S amp for audio.
- AITRIP PN532 V3-style NFC reader in SPI mode.

The same reservation is also stored as machine-readable JSON in [`config/pin-reservations.json`](../config/pin-reservations.json).

### MAX98357A I2S Amp

| Amp pin | Pi physical pin | Pi signal |
| --- | ---: | --- |
| `VIN` | 2 or 4 | 5V |
| `GND` | 14, 20, 30, 34, or 39 | GND |
| `BCLK` | 12 | `GPIO18` / PCM clock |
| `LRC` | 35 | `GPIO19` / PCM frame sync |
| `DIN` | 40 | `GPIO21` / PCM data out |
| `SD` | 36 | `GPIO16` / optional anti-pop mute gate |

Speaker wires go only to the amp screw terminals. Do not connect a passive speaker directly to Pi GPIO.

### PN532 NFC Reader, SPI Mode

This is the reservation for the AITRIP PN532 module linked in the project notes. Use the reader in SPI mode. The board may label chip select as `SS` or `CS`.

| PN532 pin | Pi physical pin | Pi signal |
| --- | ---: | --- |
| `3.3V` / `VCC` | 1 or 17 | 3.3V |
| `GND` | 6, 9, or 25 | GND |
| `SCK` | 23 | `GPIO11` / SPI0 SCLK |
| `MISO` | 21 | `GPIO9` / SPI0 MISO |
| `MOSI` | 19 | `GPIO10` / SPI0 MOSI |
| `SS` / `CS` | 24 | `GPIO8` / SPI0 CE0 |

Set the PN532 board switches/jumpers to SPI mode.

## Reserved Pin Ledger

Do not use these GPIO pins for buttons, LEDs, sensors, displays, or future features unless the audio/NFC design changes.

| Reserved for | BCM GPIO | Physical pin | Purpose |
| --- | ---: | ---: | --- |
| MAX98357A | `GPIO18` | 12 | I2S `BCLK` |
| MAX98357A | `GPIO19` | 35 | I2S `LRC` |
| MAX98357A | `GPIO21` | 40 | I2S `DIN` |
| MAX98357A | `GPIO16` | 36 | Optional `SD` shutdown/mute gate |
| AITRIP PN532 | `GPIO11` | 23 | SPI0 `SCLK` |
| AITRIP PN532 | `GPIO9` | 21 | SPI0 `MISO` |
| AITRIP PN532 | `GPIO10` | 19 | SPI0 `MOSI` |
| AITRIP PN532 | `GPIO8` | 24 | SPI0 `CE0` / `SS` / `CS` |

Power pins also reserved by convention:

| Reserved for | Physical pin | Purpose |
| --- | ---: | --- |
| MAX98357A | 2 or 4 | 5V power |
| AITRIP PN532 | 1 or 17 | 3.3V power |
| Both boards | 6, 9, 14, 20, 25, 30, 34, or 39 | Shared ground |

## Recommended Future Pins

If you add buttons or a status LED later, start here:

| Future feature | BCM GPIO | Physical pin | Notes |
| --- | ---: | ---: | --- |
| Play/pause button | `GPIO17` | 11 | Good general-purpose input |
| Volume down button | `GPIO27` | 13 | Good general-purpose input |
| Volume up button | `GPIO22` | 15 | Good general-purpose input |
| Next track button | `GPIO23` | 16 | Good general-purpose input |
| Status LED | `GPIO24` | 18 | Use a resistor |

Avoid for now:

- `GPIO2` / pin 3 and `GPIO3` / pin 5: keep I2C free for future displays/sensors.
- `GPIO14` / pin 8 and `GPIO15` / pin 10: keep UART free for serial console/debugging.
- `GPIO0` / pin 27 and `GPIO1` / pin 28: ID EEPROM pins.
- `GPIO20` / pin 38: another PCM/I2S data pin; leave unused while audio is on I2S.

## Full 40-Pin Header

Start at the pin 1 end, closest to the microSD card, then count down in pairs.

```text
Pin 1 end / microSD end

 Physical  Signal                  Physical  Signal
 --------  ---------------------   --------  ---------------------
 1         3.3V                     2         5V
 3         GPIO2 / I2C SDA          4         5V
 5         GPIO3 / I2C SCL          6         GND
 7         GPIO4                    8         GPIO14 / UART TX
 9         GND                      10        GPIO15 / UART RX
 11        GPIO17                   12        GPIO18 / I2S BCLK
 13        GPIO27                   14        GND
 15        GPIO22                   16        GPIO23
 17        3.3V                     18        GPIO24
 19        GPIO10 / SPI0 MOSI       20        GND
 21        GPIO9 / SPI0 MISO        22        GPIO25
 23        GPIO11 / SPI0 SCLK       24        GPIO8 / SPI0 CE0
 25        GND                      26        GPIO7 / SPI0 CE1
 27        GPIO0 / ID_SD            28        GPIO1 / ID_SC
 29        GPIO5                    30        GND
 31        GPIO6                    32        GPIO12 / PWM0
 33        GPIO13 / PWM1            34        GND
 35        GPIO19 / I2S LRC         36        GPIO16
 37        GPIO26                   38        GPIO20 / PCM DIN
 39        GND                      40        GPIO21 / I2S DIN
```

## Pins This Project Uses

```text
Power:
  5V      -> MAX98357A VIN
  3.3V    -> PN532 VCC
  GND     -> both boards

I2S audio:
  GPIO18 / pin 12 -> MAX98357A BCLK
  GPIO19 / pin 35 -> MAX98357A LRC
  GPIO21 / pin 40 -> MAX98357A DIN
  GPIO16 / pin 36 -> MAX98357A SD optional anti-pop mute gate

SPI NFC:
  GPIO11 / pin 23 -> PN532 SCK
  GPIO9  / pin 21 -> PN532 MISO
  GPIO10 / pin 19 -> PN532 MOSI
  GPIO8  / pin 24 -> PN532 SS/CS
```

## Safety Notes

- Pi GPIO logic is 3.3V. Do not feed 5V into a GPIO signal pin.
- Use the Pi 5V pins only for boards that expect 5V power, such as the MAX98357A `VIN`.
- Use the Pi 3.3V pins for the PN532 logic/power unless your specific board documentation says otherwise.
- Never connect a motor, relay, passive speaker, or other load directly to GPIO.
- If a jumper wire feels uncertain, stop and verify the physical pin number before powering on.

## References

- Raspberry Pi GPIO and 40-pin header docs: https://www.raspberrypi.com/documentation/computers/raspberry-pi.html#gpio-and-the-40-pin-header
- Raspberry Pi docs note that Raspberry Pi OS includes the `pinout` command via GPIO Zero.
- Raspberry Pi docs list SPI0 as `GPIO10` MOSI, `GPIO9` MISO, `GPIO11` SCLK, `GPIO8` CE0.

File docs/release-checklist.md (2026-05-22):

# v0.1 Release Checklist

Use this before publishing the repo or calling a birthday build done.

## Physical Box Tests

- [ ] Cold boot: unplug the Pi, plug it back in, wait for services, then place a known character.
- [ ] Dad Token plays the expected clip.
- [ ] Dinosaur or another toy token plays the expected clip.
- [ ] Unknown blank tag plays the friendly discovery sound.
- [ ] Reader detects stickers through the lid or top cover.
- [ ] Swapping characters stops current audio and starts the new character.
- [ ] `Stop audio` works from the dashboard.
- [ ] Speaker volume is comfortable for a child.
- [ ] No sharp edges, loose wires, exposed electronics, or loose battery cells.

## Real Setup Flow

- [ ] Open the dashboard on the home network.
- [ ] Click `Setup scan`.
- [ ] Scan a blank sticker.
- [ ] Confirm `Last seen tag` updates.
- [ ] Use the scanned UID to create a new character.
- [ ] Upload or record the first sound.
- [ ] Click `Playback`.
- [ ] Place the new character and hear the new sound.
- [ ] Delete an old audio file from the dashboard.
- [ ] Download a backup zip.

## Open-Source Hygiene

- [ ] `LICENSE` is Apache License 2.0.
- [ ] `NOTICE` names the project and contributors.
- [ ] README links the build guide, materials, wiring, admin UI, troubleshooting, and printable files.
- [ ] No private family recordings are committed.
- [ ] No copyrighted songs, audiobooks, character art, or branded model files are committed.
- [ ] No Wi-Fi credentials, SSH keys, local `.env` files, or private UIDs are committed.
- [ ] Photos/screenshots do not reveal children, home addresses, network labels, serial numbers, or private browser tabs.
- [ ] `config/characters.json` contains only fake/demo UIDs.
- [ ] Runtime files such as `config/device_state.json`, `config/guest_links.json`, and backups are ignored.

## Docs Smoke Test

- [ ] A beginner can find the shortest path in [quick-build.md](quick-build.md).
- [ ] A builder can buy parts from [materials.md](materials.md).
- [ ] A builder can wire from [wiring.md](wiring.md).
- [ ] A builder can register tags from [rf-programming.md](rf-programming.md).
- [ ] A builder can debug common problems from [troubleshooting.md](troubleshooting.md).
- [ ] NFC base dimensions are documented in [3d-printable-figures.md](3d-printable-figures.md).
- [ ] STL files listed in [../stl/README.md](../stl/README.md) exist.

## Software Checks

Run locally:

```bash
PYTHONPATH=src .venv/bin/python -m unittest discover -s tests
```

Run on the Pi:

```bash
cd /home/pi/magic-character-box
PYTHONPATH=src .venv/bin/python -m unittest discover -s tests
systemctl is-active magic-character-box magic-character-box-admin
```

## Suggested v0.1 Tag

Call it `v0.1.0` when:

- the cold boot test passes
- the real blank-sticker setup flow passes
- the repo hygiene checklist is clean
- the README and troubleshooting docs are enough for a new builder to start

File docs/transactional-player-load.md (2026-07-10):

# Transactional Player-Load Bridge

The player has an optional local request/ack bridge for installers that prepare
complete audio generations outside the player process. It is generic local
filesystem coordination: it does not fetch manifests, know a hosted service,
or contain URLs or credentials.

Maker mode is unchanged. The bridge is enabled only with:

```bash
python -m magic_box.app --transactional-config
```

or `MAGIC_BOX_TRANSACTIONAL_CONFIG=1`.

## Safety model

On the first opt-in start, the player validates the current config, its real
folders, and its selected MP3 files, then durably records that mapping as the
one-time legacy bootstrap. Later starts must prove that the on-disk config still
matches the last confirmed config and inventory. An unrequested or partially
switched config stops transactional startup before the startup sound, NFC
reader, or audio player can serve it.

While enabled:

- ordinary `characters.json` mtime changes are not loaded;
- a request may arrive before its config switch, and a config-SHA mismatch
  remains pending without disturbing the current in-memory mapping;
- the player acknowledges only after this process parses, verifies, and swaps
  the exact candidate in memory;
- an exact candidate with invalid config, selected inventory, or generation
  evidence is rejected once with a fixed reason code, then handled
  idempotently without repeatedly hashing audio;
- malformed, oversized, duplicate-key, path-escaping, symlinked, special, or
  unstable inputs fail closed;
- activation UUID reuse with different proof fields is rejected durably;
- acknowledgement and bridge state writes use fsync plus atomic replacement.

The bridge files live beside `characters.json`:

```text
story-dock-player-load-request.json
story-dock-player-load-ack.json
.magic-character-box-player-load-state.json
```

The state file is player-owned. An installer must not edit or remove it during
normal operation. Back it up together with the config before first enabling
transactional mode.

## V2 request

The request schema is `story-dock-player-load-request-v2`. It contains exactly:

```json
{
  "schema": "story-dock-player-load-request-v2",
  "activation_id": "<fresh lowercase UUID hex>",
  "operation": "activate",
  "target_kind": "manifest-revision",
  "target_label": "<opaque exact revision>",
  "manifest_revision": "<same opaque exact revision>",
  "project_root": "/canonical/project/root",
  "config_path": "/canonical/project/root/config/characters.json",
  "config_sha256": "<canonical parsed-config SHA256>",
  "generation_root": "/canonical/project/root/audio/generations/<revision>",
  "generation_metadata_sha256": "<exact metadata-file SHA256>",
  "selected_inventory_sha256": "<canonical selected-binding inventory SHA256>",
  "selected_binding_count": 1,
  "selected_folder_count": 1,
  "selected_file_count": 1
}
```

Rollback uses `operation: "rollback"`. A versioned rollback keeps
`target_kind: "manifest-revision"` and supplies the previous generation proof.
A one-time legacy rollback uses `target_kind: "legacy-config"`, an opaque
`target_label` such as `legacy:<config-sha>`, and null values for
`manifest_revision`, `generation_root`, and `generation_metadata_sha256`.

All paths are exact canonical absolute real paths. For a manifest target,
`target_label` and `manifest_revision` must match exactly. The player makes no
assumption about the revision's length or naming scheme.

## Canonical fingerprints

Canonical JSON uses UTF-8 with sorted object keys, `ensure_ascii=True`, and
compact `,` / `:` separators.

`config_sha256` hashes the parsed config object serialized that way. Duplicate
JSON keys and duplicate normalized NFC UIDs are rejected.

The selected inventory is a JSON list sorted by normalized UID. Each item is:

```json
{
  "uid": "04-A1",
  "mode": "first",
  "folder": "audio/example",
  "files": [
    {
      "path": "audio/example/memo.mp3",
      "byte_count": 123,
      "sha256": "<exact regular-file SHA256>"
    }
  ]
}
```

Folders and files are relative POSIX paths beneath the fixed real project root.
Files are the sorted immediate regular `.mp3` entries the current player can
actually select. The three counts are the number of bindings, unique folders,
and unique playable paths. The SHA is over the canonical list.
Zero-byte files are included in this whole-config proof so existing maker
placeholder files do not prevent the one-time legacy bootstrap.

For a generation target, the player also hashes the exact
`.story-dock-generation.json` bytes and independently walks the full generation
tree. Its regular-file paths, byte counts, and SHA256 values must exactly match
the metadata `file_inventory`; links, special files, extra files, and missing
files reject the activation. Unlike legacy placeholders, every managed
generation file must be non-empty. Every selected playable inside the managed
generation must belong to that exact inventory.

## V2 acknowledgement

A loaded ack uses `story-dock-player-load-ack-v2`, repeats every request proof
field exactly, sets `status: "loaded"`, and adds:

- `player_instance_id`: fresh lowercase UUID hex for this process;
- `player_pid`: the current positive process ID;
- `load_sequence`: a positive per-process load sequence;
- `loaded_at`: UTC timestamp ending in `Z`.

A valid request whose exact candidate fails permanent validation gets
`status: "rejected"`, the same proof/process fields, a nonnegative load
sequence, and one fixed `reason_code`:

- `candidate-config-invalid`
- `selected-inventory-invalid`
- `generation-invalid`

The machine-readable parity fixture is
[`tests/fixtures/player-load-v2-contract.json`](../tests/fixtures/player-load-v2-contract.json).

## Rollout

Do not enable this flag merely to get ordinary maker hot reload. It is intended
for a coordinated installer/client that implements the exact V2 contract.
Before enabling it on a physical box, back up the runtime, test request-first
activation and rollback, then verify offline playback and a cold restart. The
systemd service remains unmodified and maker installs stay opt-out by default.

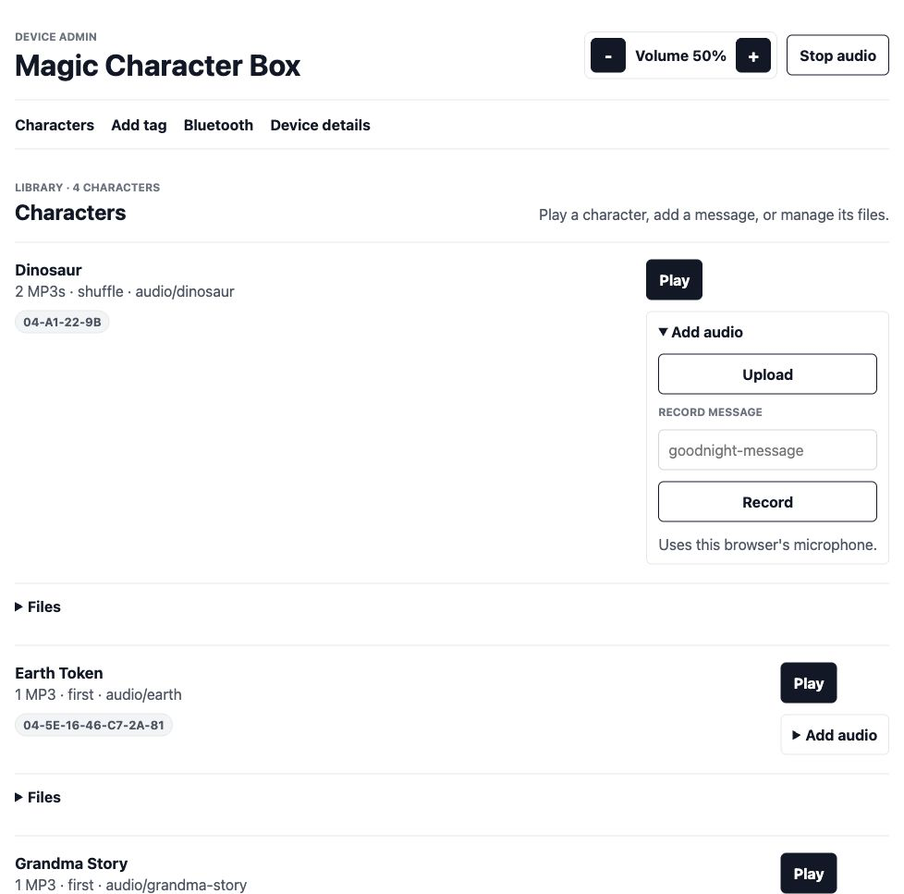
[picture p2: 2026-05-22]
docs/assets/screenshots/software-admin-library.png

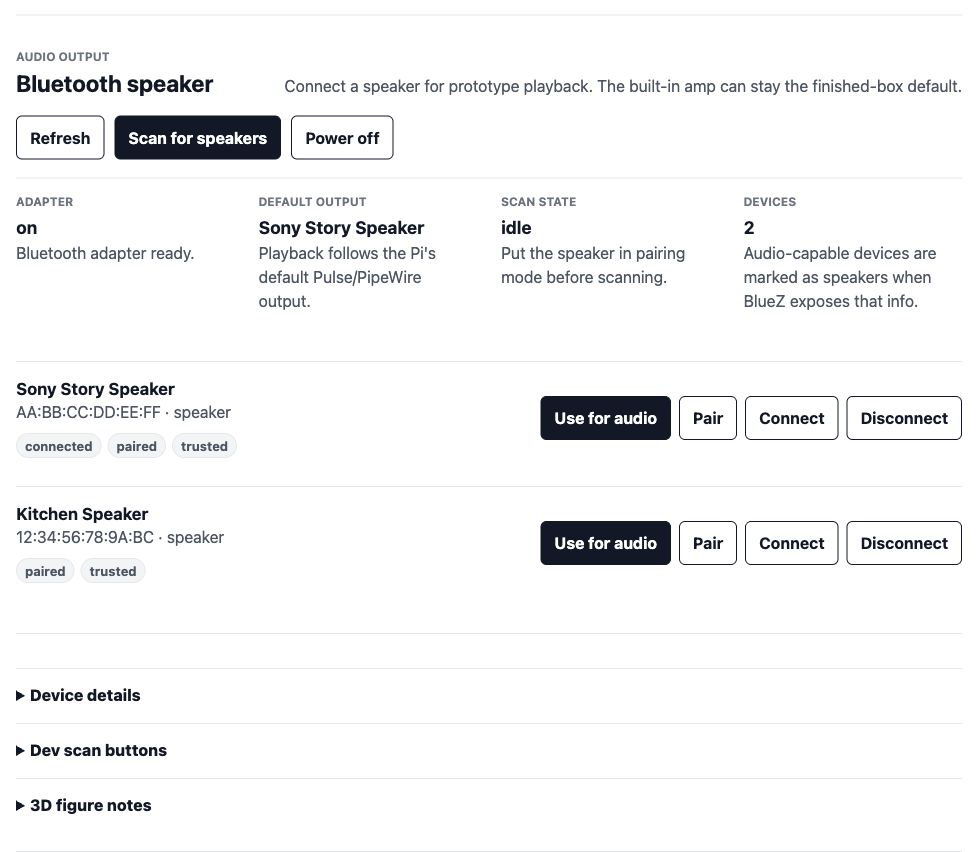
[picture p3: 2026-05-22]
docs/assets/screenshots/software-bluetooth-control.png

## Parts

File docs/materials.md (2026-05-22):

# Materials List

This bill of materials is for the first public Magic Character Box build: Raspberry Pi Zero 2 W or Zero 2 WH, PN532 NFC/RFID reader, MAX98357A I2S amp, passive speaker, and a printed or simple handmade enclosure.

Exact brands do not matter. Match the part type, voltage, and interface.

## Core Electronics

| Qty | Item | Use | Notes |
| ---: | --- | --- | --- |
| 1 | Raspberry Pi Zero 2 W or Zero 2 WH | Main computer | The `WH`/with-headers version saves soldering. Zero 2 W without headers needs a 40-pin male header soldered on. |
| 1 | microSD card, 16 GB or larger | Pi OS and local audio | 32 GB gives more room for stories and songs. |
| 1 | 5V USB power supply, 2A or better | Powers the Pi and amp | Use a known-good charger. Weak power causes weird audio and boot issues. |
| 1 | PN532 NFC/RFID reader module | Reads character/tag UIDs | Use a 13.56 MHz PN532 board that supports SPI mode. AITRIP/Elechouse-style PN532 V3 boards work. |
| 3-10 | NTAG213/215/216 NFC stickers or fobs | Hidden IDs for characters | Round 25 mm stickers fit the printable figure base. |
| 1 | MAX98357A I2S DAC/amp breakout board | Drives the passive speaker | Do not connect a passive speaker directly to the Pi. |
| 1 | Passive speaker | Sound output | 4-8 ohm is ideal. A larger speaker cabinet can sound much better than a tiny bare driver. |

## Headers, Wires, And Small Connectors

Most frustrating "bad part" issues in this project are actually loose jumper wires or missing headers. For a first build, buy more jumpers than the exact count.

| Qty | Item | Use | Notes |
| ---: | --- | --- | --- |
| 1 | 40-pin male header for Pi Zero | Pi GPIO access | Not needed if you buy a Zero 2 WH or Zero WH with headers already soldered. |
| 1-2 | 0.1 inch male header strips | PN532/MAX98357A pins | Many breakout boards include unsoldered header strips. |
| 12+ | Female-to-female Dupont jumper wires, 10-20 cm | Pi-to-PN532 and Pi-to-MAX98357A wiring | This is the main type when the Pi and breakout boards both have male header pins. |
| 4-6 | Extra female-to-female jumpers | Ground sharing, SD mute, experiments | Having spares saves a trip when one wire is flaky. |
| Optional | Female-to-male Dupont jumpers | Breadboard/prototype wiring | Useful if you test through a breadboard before putting parts in the case. |
| Optional | 22-26 AWG stranded wire | Speaker leads or cleaner internal runs | Use this when the speaker needs longer or more flexible wires than Dupont jumpers. |
| Optional | 2-pin JST connector pair or screw-terminal pigtail | Removable speaker connection | Handy if you want the speaker/case to unplug cleanly. |
| Optional | Heat shrink, tape, or small zip ties | Strain relief | Keeps kid-box vibration and lid removal from tugging pins loose. |

### Wire Count For The Recommended Build

Minimum Pi-to-board jumpers:

- MAX98357A amp: `VIN`, `GND`, `BCLK`, `LRC`, `DIN`, and optional/recommended `SD` mute = 5-6 wires.
- PN532 reader: `3.3V`, `GND`, `SCK`, `MISO`, `MOSI`, `SS/CS` = 6 wires.
- Speaker: 2 wires from the MAX98357A speaker terminal to the passive speaker.

So the practical minimum is 11-12 female-to-female jumpers plus speaker wire. Buy a 20-pack or 40-pack.

## Board Options

The project is written for Raspberry Pi OS first. Other Linux boards can work, but the further you get from Raspberry Pi, the more likely you are to debug GPIO names, SPI overlays, I2S audio, and Python hardware libraries instead of building the box.

| Board | Recommendation | Notes |
| --- | --- | --- |
| Raspberry Pi Zero 2 W / Zero 2 WH | Best default | Small, cheap, Wi-Fi/Bluetooth, 40-pin GPIO, enough CPU for Flask admin, `ffmpeg`, and smooth playback. |
| Raspberry Pi Zero W / Zero WH | Works for basic playback | Same 512 MB RAM class and 40-pin header, but single-core. Good if you already own one; expect slower installs, uploads, and audio conversion. Prefer `WH` if you do not want to solder the header. |
| Raspberry Pi 3A+ | Good alternate | Faster than Zero W, built-in wireless, 40-pin GPIO, but physically larger than a Zero. |
| Used Raspberry Pi 3B/3B+/4B | Easy but bigger | Great for a bench demo and plenty fast. Larger board and higher power draw make the enclosure less cute. |
| Raspberry Pi 5 | Overkill | Works, but costs more, draws more power, and does not improve the core toy experience. |
| Radxa Zero 3W | Experimental contributor path | Similar small-board idea with 40-pin GPIO, often more RAM/CPU. Not a drop-in Raspberry Pi OS target; expect board-specific SPI/I2S setup. |
| Orange Pi Zero 2W | Experimental contributor path | Cheap and small, with community OS options such as DietPi. Treat as a porting target, not the beginner tutorial path. |
| Raspberry Pi Pico W / ESP32 | Not a drop-in replacement | Microcontrollers can do a simpler NFC/audio toy, but not this Linux/Python/Flask/`mpg123` software stack without a rewrite. |

If you use a non-Pi board, the board needs:

- Linux with Python 3.10+.
- Reliable Wi-Fi or Ethernet for the admin page.
- SPI GPIO access for the PN532.
- I2S audio support for MAX98357A, or a USB audio device/speaker instead.
- 3.3V GPIO logic for NFC signals.

## Enclosure And Figure Parts

| Qty | Item | Use | Notes |
| ---: | --- | --- | --- |
| 1 | Printed sidecar enclosure body | Electronics case | Use [`../stl/small-sidecar-enclosure-body.stl`](../stl/small-sidecar-enclosure-body.stl). |
| 1 | Printed sidecar enclosure lid | NFC reader/top cover | Use [`../stl/small-sidecar-enclosure-lid.stl`](../stl/small-sidecar-enclosure-lid.stl). |
| 4 | M2.5 x 8 mm screws | Lid screws | Small self-tapping screws also work if they fit your print. |
| 1 | Hook-and-loop tape | Mount sidecar to speaker cabinet | Use a generous patch so the module does not twist loose. |
| 3-5 | Toy figures, tokens, or printed bases | Character objects | Use generic/original figures for public tutorial photos. |
| 3-5 | Printed NFC figure bases | Holds NFC stickers | Use [`../stl/nfc-character-base-flat.stl`](../stl/nfc-character-base-flat.stl). |
| 1 roll | Thin felt, tape, or label paper | Covers sticker recess | Helps keep stickers from peeling or scraping. |

The included NFC figure base is sized for 25 mm round stickers. See [3d-printable-figures.md](3d-printable-figures.md#included-base-specs) for exact dimensions before buying larger tags.

## Tools

- Computer for flashing Raspberry Pi OS and copying the repo.
- 3D printer, or a print service.
- Small Phillips screwdriver.
- Wire cutters or flush cutters.
- Soldering iron if your Pi header, speaker connector, or amp board is not already soldered.
- Multimeter, optional but useful for checking 5V, 3.3V, and ground.
- Phone or laptop on the same network for the admin page.

## Software And Files

- Raspberry Pi OS Lite or Desktop.
- Python 3.10 or newer.
- `mpg123` for MP3 playback.
- `ffmpeg` for uploaded/recorded audio conversion.
- This repo copied to `/home/pi/magic-character-box` or another known folder.
- Local audio files you have the right to use.

The install script handles the system packages and Python environment:

```bash
./scripts/install_pi.sh
```

## Optional Upgrades

| Item | Why add it |
| --- | --- |
| Bigger passive speaker cabinet | Better sound without changing the software. |
| USB power bank | Portable prototype power, if it is sealed and kid-safe. |
| Arcade button | Future play/pause or next-track control. |
| Status LED plus resistor | Future boot/scan/play feedback. |
| Short JST or Dupont extension leads | Cleaner removable wiring inside the case. |
| Heat-set inserts | More durable screw points than plastic pilot holes. |

## Do Not Use

- A bare passive speaker connected directly to Raspberry Pi GPIO.
- Loose LiPo batteries in a kid-facing prototype.
- Metal enclosures or metal plates between the NFC tag and PN532 reader.
- Copyrighted songs, character art, or private recordings in a public repo.
- UHF RFID tags/readers. This project expects 13.56 MHz NFC tags read by a PN532-style reader.

## First Shopping Pass

If starting from nothing, buy or gather:

1. Raspberry Pi Zero 2 W/WH, microSD card, and 5V power supply.
2. PN532 NFC reader plus NTAG213/215/216 stickers.
3. MAX98357A amp plus passive speaker.
4. 20+ female-to-female jumper wires, headers, speaker wire, and small screws.
5. Printed enclosure parts, or a cardboard/project box for the ugly demo.

Then build in this order:

1. Software mock mode.
2. PN532 scan test.
3. MAX98357A audio test.
4. Register stickers.
5. Print or assemble the enclosure.

## Source Notes

- Raspberry Pi lists Zero W as a 1GHz single-core, 512 MB board with wireless and a HAT-compatible 40-pin header.
- Raspberry Pi lists Zero 2 W as a 1GHz quad-core Arm Cortex-A53, 512 MB board with wireless and a HAT-compatible 40-pin header footprint.
- Adafruit's PN532 Python guide recommends SPI on Raspberry Pi because I2C and UART are not reliable for that breakout on Pi.
- Adafruit's MAX98357A guide describes it as an I2S class-D mono amp that works with Raspberry Pi and can drive 4-8 ohm speakers from a 5V supply.

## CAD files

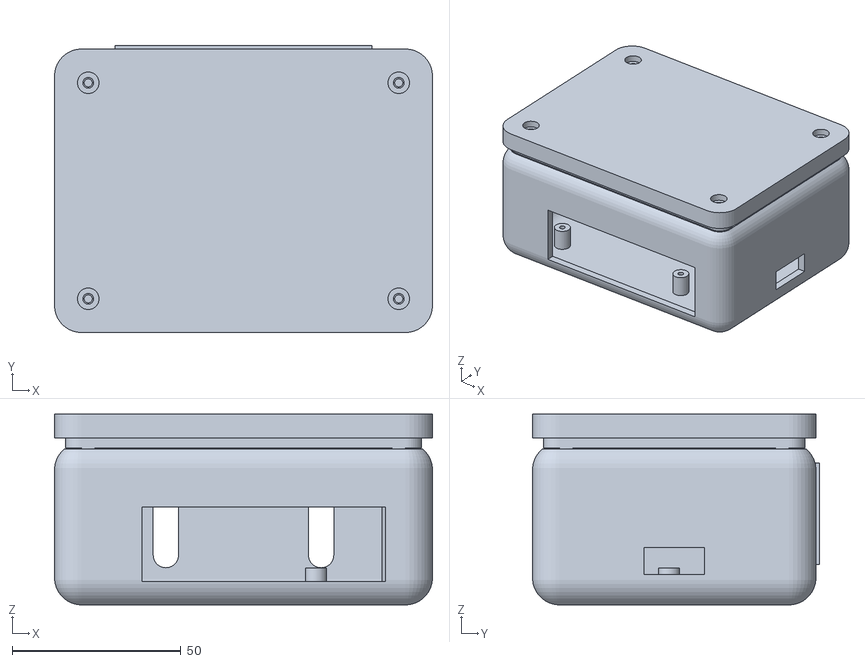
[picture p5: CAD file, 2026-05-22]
stl/small-sidecar-enclosure-assembly.stl
112.0 x 85.0 x 56.5

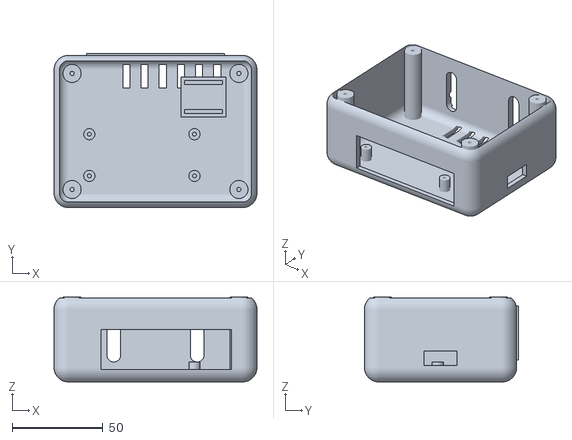
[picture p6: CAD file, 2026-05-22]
stl/small-sidecar-enclosure-body.stl
112.0 x 85.0 x 46.8

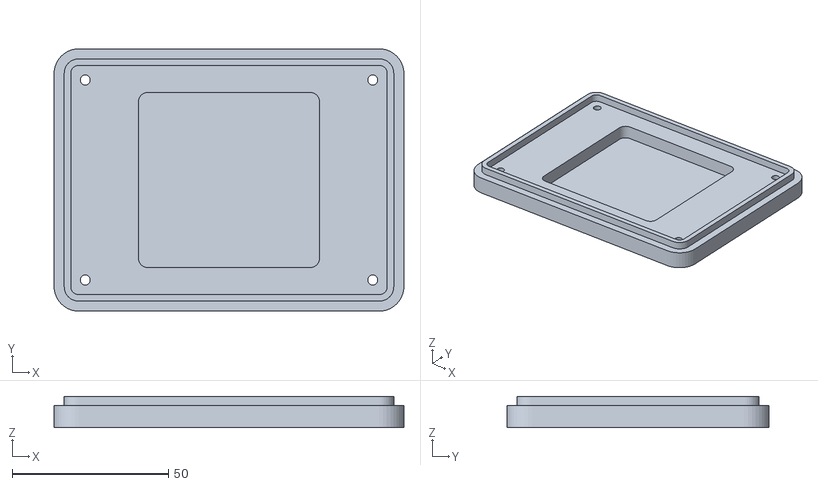
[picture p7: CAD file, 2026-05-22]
stl/small-sidecar-enclosure-lid.stl
112.0 x 84.0 x 10.0

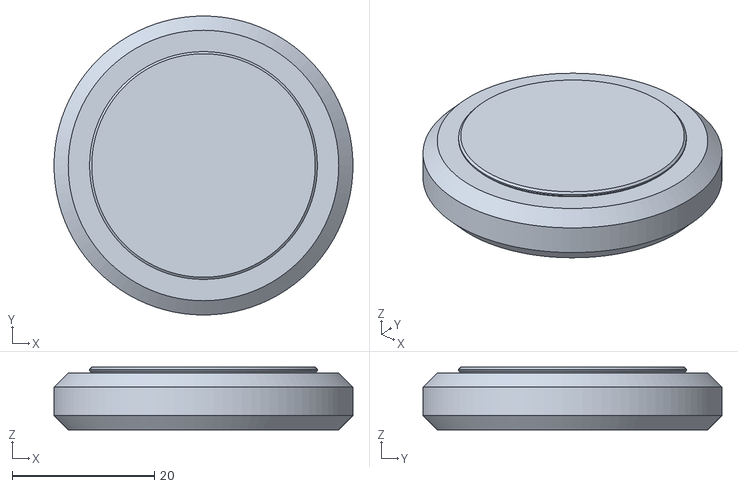
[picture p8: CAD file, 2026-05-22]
stl/nfc-character-base-flat.stl
42.0 x 42.0 x 8.80

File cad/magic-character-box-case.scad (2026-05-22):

// Magic Character Box enclosure
//
// Print parts:
//   openscad -o build/magic-character-box-body.stl -D 'part="body"' magic-character-box-case.scad
//   openscad -o build/magic-character-box-lid.stl  -D 'part="lid"'  magic-character-box-case.scad
//   openscad -o build/magic-character-box-sidecar-body.stl -D 'variant="sidecar"' -D 'part="body"' magic-character-box-case.scad
//
// Units: millimeters.

$fn = 40;

part = "assembly"; // "assembly", "body", or "lid"
variant = "standalone"; // "standalone" or "sidecar"
sidecar = variant == "sidecar";

case_w = sidecar ? 112 : 124;
case_d = sidecar ? 84 : 96;
body_h = sidecar ? 48 : 58;
lid_t = 7;
wall = 3;
corner_r = sidecar ? 8 : 10;
fit_clearance = 0.55;

screw_offset = sidecar ? 10 : 12;
screw_post_d = 10;
screw_pilot_d = 2.4;      // pilot for M2.5-ish self tapping screws
screw_lid_clearance_d = 3.2;
screw_counterbore_d = 6.4;
screw_counterbore_h = 2.0;

lid_lip_depth = 3.2;
lid_lip_wall = 2.1;

pi_board = [65, 30];
pi_origin = sidecar ? [16, 14] : [18, 12];
pi_hole_offset = 3.5;
pi_standoff_h = sidecar ? 8 : 5;

pn532_board = [43, 41];
pn532_tray_clearance = 1.8;
pn532_recess = [58, 56];
pn532_recess_skin = 1.6;
pn532_recess_r = 3;

amp_pad = [25, 22];
amp_pad_origin = sidecar ? [70, 50] : [86, 14];

speaker_center_z = 30;
speaker_center_y = case_d / 2;
speaker_hole_d = 4.2;
speaker_hole_spacing = 8;
speaker_pattern_d = 43;

velcro_pad_w = 76;
velcro_pad_h = 30;
velcro_pad_t = 1.2;
velcro_pad_z = 12;

strap_slot_w = 6;
strap_slot_h = 26;
strap_slot_spacing = 46;

speaker_wire_exit = [wall + 4, 18, 8];

cable_window_z = sidecar ? 7 : 10;
cable_window_h = sidecar ? 22 : 16;

module rounded_box(size, r) {
  translate([r, r, r])
    minkowski() {
      cube([size[0] - 2 * r, size[1] - 2 * r, size[2] - 2 * r]);
      sphere(r = r);
    }
}

module rounded_prism(size, r) {
  translate([r, r, 0])
    linear_extrude(height = size[2])
      offset(r = r)
        square([size[0] - 2 * r, size[1] - 2 * r]);
}

module screw_positions() {
  for (p = [
    [screw_offset, screw_offset],
    [case_w - screw_offset, screw_offset],
    [screw_offset, case_d - screw_offset],
    [case_w - screw_offset, case_d - screw_offset]
  ]) {
    translate([p[0], p[1], 0]) children();
  }
}

module standoff(x, y, h = 5, d = 6, hole_d = 2.2) {
  translate([x, y, wall - 0.2])
    difference() {
      cylinder(h = h + 0.2, d = d);
      translate([0, 0, -0.2])
        cylinder(h = h + 0.6, d = hole_d);
    }
}

module pi_standoffs() {
  for (x = [pi_hole_offset, pi_board[0] - pi_hole_offset])
    for (y = [pi_hole_offset, pi_board[1] - pi_hole_offset])
      standoff(pi_origin[0] + x, pi_origin[1] + y, pi_standoff_h, 6.2, 2.2);
}

module amp_pad_mount() {
  translate([amp_pad_origin[0], amp_pad_origin[1], wall - 0.2])
    difference() {
      union() {
        cube([amp_pad[0], amp_pad[1], 1.6]);
        translate([2, 2, 1.4]) cube([amp_pad[0] - 4, 2, 2.2]);
        translate([2, amp_pad[1] - 4, 1.4]) cube([amp_pad[0] - 4, 2, 2.2]);
      }
      translate([amp_pad[0] / 2 - 1.2, -1, 1.8])
        cube([2.4, amp_pad[1] + 2, 1.6]);
    }
}

module body_shell() {
  difference() {
    rounded_box([case_w, case_d, body_h], corner_r);
    translate([wall, wall, wall])
      rounded_box([case_w - 2 * wall, case_d - 2 * wall, body_h + wall], corner_r - wall);
  }
}

module sidecar_velcro_pad() {
  if (sidecar)
    translate([(case_w - velcro_pad_w) / 2, case_d - 0.15, velcro_pad_z])
      cube([velcro_pad_w, velcro_pad_t, velcro_pad_h]);
}

module screw_posts() {
  screw_positions()
    translate([0, 0, wall - 0.2])
      difference() {
        cylinder(h = body_h - wall - 1.0, d = screw_post_d);
        translate([0, 0, -0.2])
          cylinder(h = body_h - wall + 0.4, d = screw_pilot_d);
      }
}

module speaker_holes() {
  for (dy = [-16 : speaker_hole_spacing : 16])
    for (dz = [-16 : speaker_hole_spacing : 16])
      if (sqrt(dy * dy + dz * dz) <= speaker_pattern_d / 2)
        translate([case_w / 2, speaker_center_y + dy, speaker_center_z + dz])
          rotate([0, 90, 0])
            cylinder(h = case_w + 6, d = speaker_hole_d, center = true);
}

module cable_window() {
  // Broad front window for USB power/data cable access during prototyping.
  translate([26, -1, cable_window_z])
    cube([72, wall + 2, cable_window_h]);
}

module bottom_air_slots() {
  for (x = [38 : 10 : 88])
    translate([x, case_d - 18, -1])
      cube([4, 30, wall + 2]);
}

module rear_rounded_slot_cut(x, z, w, h, cut_depth = wall + velcro_pad_t + 4) {
  translate([x - w / 2, case_d - wall - 1, z - h / 2 + w / 2])
    cube([w, cut_depth, h - w]);
  for (dz = [-h / 2 + w / 2, h / 2 - w / 2])
    translate([x, case_d + velcro_pad_t / 2, z + dz])
      rotate([90, 0, 0])
        cylinder(h = cut_depth, d = w, center = true);
}

module rear_round_dimple_cut(x, z, d, cut_depth = velcro_pad_t + 0.8) {
  translate([x, case_d + velcro_pad_t / 2, z])
    rotate([90, 0, 0])
      cylinder(h = cut_depth, d = d, center = true);
}

module sidecar_face_cuts() {
  if (sidecar) {
    // The two strap slots double as friendly rounded eyes.
    for (x = [case_w / 2 - strap_slot_spacing / 2, case_w / 2 + strap_slot_spacing / 2])
      rear_rounded_slot_cut(x, body_h / 2, strap_slot_w + 1.5, strap_slot_h);

    // A dotted smile engraved into the raised rear pad.
    for (a = [-52 : 13 : 52])
      rear_round_dimple_cut(
        case_w / 2 + 18 * sin(a),
        16.5 + 5.5 * (1 - cos(a)),
        3.0
      );

    // Small cheek dimples. They stay shallow so the pad still has plenty of
    // surface for tape/Velcro if this side is mounted against a speaker.
    for (x = [case_w / 2 - 28, case_w / 2 + 28])
      rear_round_dimple_cut(x, 19, 4.2);
  }
}

module sidecar_speaker_wire_exit() {
  if (sidecar)
    translate([case_w - wall - 1, case_d / 2 - speaker_wire_exit[1] / 2, 9])
      cube(speaker_wire_exit);
}

module body() {
  difference() {
    union() {
      body_shell();
      sidecar_velcro_pad();
      screw_posts();
      pi_standoffs();
      amp_pad_mount();
    }
    if (!sidecar)
      speaker_holes();
    cable_window();
    bottom_air_slots();
    sidecar_face_cuts();
    sidecar_speaker_wire_exit();
  }
}

module lid_lip() {
  lip_w = case_w - 2 * wall - fit_clearance;
  lip_d = case_d - 2 * wall - fit_clearance;
  translate([wall + fit_clearance / 2, wall + fit_clearance / 2, -lid_lip_depth + 0.2])
    difference() {
      rounded_prism([lip_w, lip_d, lid_lip_depth], corner_r - wall - 0.5);
      translate([lid_lip_wall, lid_lip_wall, -0.2])
        rounded_prism([
          lip_w - 2 * lid_lip_wall,
          lip_d - 2 * lid_lip_wall,
          lid_lip_depth + 0.4
        ], max(1.5, corner_r - wall - lid_lip_wall - 0.5));
    }
}

module nfc_target_ring() {
  translate([case_w / 2, case_d / 2, lid_t - 0.1])
    difference() {
      cylinder(h = 0.8, d = 54);
      translate([0, 0, -0.1])
        cylinder(h = 1.0, d = 44);
    }
}

module pn532_lid_tray() {
  tray_w = pn532_board[0] + 2 * pn532_tray_clearance;
  tray_d = pn532_board[1] + 2 * pn532_tray_clearance;
  rail_h = 2.2;
  rail_w = 2.2;
  x0 = case_w / 2 - tray_w / 2;
  y0 = case_d / 2 - tray_d / 2;
  z0 = -rail_h + 0.2;

  // Four low rails: hold the PN532 board close to the top without covering the antenna.
  translate([x0, y0, z0]) cube([tray_w, rail_w, rail_h]);
  translate([x0, y0 + tray_d - rail_w, z0]) cube([tray_w, rail_w, rail_h]);
  translate([x0, y0, z0]) cube([rail_w, tray_d, rail_h]);
  translate([x0 + tray_w - rail_w, y0, z0]) cube([rail_w, tray_d, rail_h]);
}

module pn532_lid_recess_cut() {
  // Sidecar build: maximize NFC range by letting the PN532 sit almost flush
  // against a thin plastic window. Glue/tape the board into the pocket.
  translate([
    case_w / 2 - pn532_recess[0] / 2,
    case_d / 2 - pn532_recess[1] / 2,
    -0.05
  ])
    rounded_prism([
      pn532_recess[0],
      pn532_recess[1],
      lid_t - pn532_recess_skin + 0.1
    ], pn532_recess_r);
}

module lid_screw_holes() {
  screw_positions()
    translate([0, 0, -lid_lip_depth - 0.5])
      union() {
        cylinder(h = lid_t + lid_lip_depth + 1.5, d = screw_lid_clearance_d);
        translate([0, 0, lid_lip_depth + lid_t - screw_counterbore_h])
          cylinder(h = screw_counterbore_h + 1, d = screw_counterbore_d);
      }
}

module lid_model(show_target_ring = true) {
  difference() {
    union() {
      rounded_prism([case_w, case_d, lid_t], corner_r);
      lid_lip();
      if (show_target_ring)
        nfc_target_ring();
      if (!sidecar)
        pn532_lid_tray();
    }
    lid_screw_holes();
    if (sidecar)
      pn532_lid_recess_cut();
  }
}

module lid_print_flat_top() {
  // Print with the visible top face on the bed. The sidecar lid omits the
  // raised NFC target ring so this exported STL has a single flat bed face.
  translate([0, case_d, lid_t])
    rotate([180, 0, 0])
      lid_model(show_target_ring = false);
}
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

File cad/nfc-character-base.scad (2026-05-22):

// Reusable NFC character base for Magic Character Box figures.
//
// The default 42 mm puck has an underside recess for a 25 mm NFC sticker,
// plus a clean top landing pad where a generated or hand-modeled figure can
// be merged in Blender, Tinkercad, Bambu Studio, PrusaSlicer, or OpenSCAD.
//
// Render examples:
//   openscad -o build/nfc-character-base-flat.stl   -D 'part="flat"'   nfc-character-base.scad
//   openscad -o build/nfc-character-base-peg.stl    -D 'part="peg"'    nfc-character-base.scad
//   openscad -o build/nfc-character-base-socket.stl -D 'part="socket"' nfc-character-base.scad
//
// Units: millimeters.

$fn = 96;

part = "flat"; // "flat", "peg", "socket", or "demo"

base_d = 42;
base_h = 8;
base_bevel = 2;

top_pad_d = 32;
top_pad_h = 0.8;
top_pad_bevel = 0.4;

sticker_d = 25;
sticker_clearance = 1.4;
sticker_recess_depth = 0.8;
sticker_notch_d = 7;

connector_peg_d = 7.8;
connector_peg_h = 3.2;
connector_socket_d = 8.4;
connector_socket_depth = 3.4;

// If you want to union a model directly in OpenSCAD, put its STL path here and
// tune the scale/offset. Most workflows will instead merge the exported base
// and the figure STL in a slicer or mesh editor.
figure_file = "";
figure_scale = [1, 1, 1];
figure_offset = [0, 0, 0];

module bevelled_cylinder(d, h, bevel) {
  r = d / 2;
  b = min(bevel, min(r - 0.1, h / 2 - 0.1));
  rotate_extrude(convexity = 10)
    polygon(points = [
      [0, 0],
      [r - b, 0],
      [r, b],
      [r, h - b],
      [r - b, h],
      [0, h]
    ]);
}

module sticker_recess() {
  pocket_d = sticker_d + sticker_clearance;
  translate([0, 0, -0.05])
    cylinder(h = sticker_recess_depth + 0.1, d = pocket_d);

  // Small fingertip/notch relief so tape or a sticker edge can be lifted later.
  translate([0, -pocket_d / 2, -0.05])
    cylinder(h = sticker_recess_depth + 0.1, d = sticker_notch_d);
}

module top_landing_pad() {
  translate([0, 0, base_h - 0.01])
    bevelled_cylinder(top_pad_d, top_pad_h + 0.01, top_pad_bevel);
}

module connector_peg() {
  translate([0, 0, base_h + top_pad_h - 0.01])
    bevelled_cylinder(connector_peg_d, connector_peg_h + 0.01, 0.6);
}

module connector_socket_cut() {
  translate([0, 0, base_h + top_pad_h - connector_socket_depth])
    cylinder(h = connector_socket_depth + 0.2, d = connector_socket_d);
}

module base_solid(connector = "flat") {
  union() {
    bevelled_cylinder(base_d, base_h, base_bevel);
    top_landing_pad();
    if (connector == "peg") {
      connector_peg();
    }
  }
}

module nfc_character_base(connector = "flat") {
  difference() {
    base_solid(connector);
    sticker_recess();
    if (connector == "socket") {
      connector_socket_cut();
    }
  }
}

module imported_figure() {
  if (figure_file != "") {
    translate([figure_offset[0], figure_offset[1], base_h + top_pad_h + figure_offset[2]])
      scale(figure_scale)
        import(figure_file, convexity = 10);
  }
}

module demo_figure() {
  translate([0, 0, base_h + top_pad_h])
    union() {
      cylinder(h = 18, d = 11);
      translate([0, 0, 21])
        sphere(d = 15);
      translate([-8, -2, 11])
        rotate([0, 80, 0])
          cylinder(h = 12, d = 3.5);
      translate([8, -2, 11])
        rotate([0, -80, 0])
          cylinder(h = 12, d = 3.5);
    }
}

if (part == "peg") {
  nfc_character_base("peg");
} else if (part == "socket") {
  nfc_character_base("socket");
} else if (part == "demo") {
  union() {
    nfc_character_base("flat");
    demo_figure();
    imported_figure();
  }
} else {
  union() {
    nfc_character_base("flat");
    imported_figure();
  }
}

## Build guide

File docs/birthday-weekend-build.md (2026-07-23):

# Birthday Weekend Build

This is the shortest path to a giftable Magic Character Box. It favors the magical moment over a perfect enclosure.

## Goal

By party time, the child can:

1. Turn on the box and hear the startup chime.
2. Place a character on top.
3. Hear that character's sound, song, story, or family message.
4. Help teach at least one new character from the dashboard.

## Do Exactly This

### 1. Prepare The Pi

- Flash Raspberry Pi OS.
- Copy this repo to `/home/pi/magic-character-box`.
- Run `./scripts/install_pi.sh`.
- Enable SPI with `sudo raspi-config`.
- Reboot.

### 2. Generate The Magic Sounds

```bash
cd /home/pi/magic-character-box
./scripts/generate_system_sounds.sh
```

The box uses:

- `audio/system/startup-chime.mp3` when the service starts.
- `audio/system/unknown-tag.mp3` when it sees an unregistered tag.
- Continuous zero PCM between clips to keep the audio path warm; `silence.mp3` remains a useful manual test asset.

For extra magic, replace `unknown-tag.mp3` with a recorded voice saying "I found a new character."

### 3. Wire Only The Required Hardware

- Pi Zero 2 W or Zero 2 WH.
- PN532 reader in SPI mode.
- MAX98357A amp and passive speaker.
- USB power.

Use [wiring.md](wiring.md) and [pi-zero-2w-pin-map.md](pi-zero-2w-pin-map.md). Do not add buttons or battery power for the first gift version.

### 4. Make Three Characters

Start with:

- One toy character.
- One mystery token.
- One family token.

Attach NFC stickers to the underside of a toy, token, or printed base.

### 5. Teach The Characters

Open:

```text
http://<pi-hostname-or-ip>:8080
```

Use the dashboard:

1. Click `Setup scan`.
2. Go to `Teach character`.
3. Scan a tag.
4. Name it.
5. Save it.
6. Add its first sound.
7. Click `Playback`.

### 6. Box It Ugly First

Cardboard, a project box, or the printed sidecar enclosure is enough. The important part is that:

- The PN532 sits directly under the "place character here" spot.
- Wires are strain-relieved.
- The Pi and amp are not exposed to the child.
- USB power is adult-accessible.

## Done Is Better Than Perfect

For the birthday moment, skip:

- Battery power.
- Bluetooth.
- Web accounts.
- Fancy case finishing.
- More than one button.
- A big music library.

The magic is the physical ritual plus the personal recordings.

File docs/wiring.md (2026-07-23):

# Wiring Notes

For a fuller GPIO reference, keep [pi-zero-2w-pin-map.md](pi-zero-2w-pin-map.md) open while wiring.

The project reserves pins for two always-installed boards:

- `MAX98357A` I2S amp.
- AITRIP PN532 NFC reader in SPI mode.

The reservation ledger is in [pi-zero-2w-pin-map.md](pi-zero-2w-pin-map.md) and [config/pin-reservations.json](../config/pin-reservations.json).

## Audio: MAX98357A To Raspberry Pi Zero 2 W

The Pi does not drive a passive speaker directly. The Pi powers the MAX98357A amp and sends I2S audio; the amp drives the speaker.

```text
MAX98357A VIN  -> Pi 5V
MAX98357A GND  -> Pi GND
MAX98357A BCLK -> GPIO18 / pin 12
MAX98357A LRC  -> GPIO19 / pin 35
MAX98357A DIN  -> GPIO21 / pin 40
MAX98357A SD   -> GPIO16 / pin 36 optional, recommended for anti-pop mute
Speaker +      -> MAX98357A speaker +
Speaker -      -> MAX98357A speaker -
```

Use a stable 5V charger with enough headroom for the Pi, PN532, and speaker amp. For this build, use 5V 2A or better.

After enabling/configuring I2S audio for the MAX98357A, reboot before testing playback.

### Anti-Pop Amp Mute Gate

For the quietest finished box, do not tie `SD` directly to 3.3V. Wire `MAX98357A SD` to `GPIO16 / physical pin 36` instead. The software can then keep the amp muted while Linux boots, enable it once the service is ready, and avoid waking the amp right before every clip.

Add this to `/boot/firmware/config.txt` so the Pi holds GPIO16 low early in boot:

```text
gpio=16=op,dl
```

The systemd services set `MAGIC_BOX_AMP_SD_GPIO=16`, so after this rewire the app and admin page will automatically use the mute gate. The player services also set `MAGIC_BOX_AMP_MUTE_BETWEEN_TRACKS=0`, leaving the amp enabled between clips because some MAX98357A boards make a click when `SD` wakes the amp. If your board still pops before Linux applies the GPIO setting, add a physical pulldown resistor from `SD` to `GND` as a hardware refinement.

The deployed Pi player service gives one long-lived `aplay` process exclusive ownership of `plughw:CARD=MAX98357A,DEV=0`. It continuously receives fixed 48 kHz, stereo, signed-16 PCM: zero PCM while idle and decoded audio while a clip is playing. The player decodes each MP3 to raw PCM without opening ALSA itself. This keeps the I2S clocks active between taps without a user-session Pulse/PipeWire socket, a second ALSA client, or the retired `dmix`/keeper stream that distorted some builds.

## NFC: PN532 To Raspberry Pi Zero 2 W

Use SPI for the AITRIP PN532 reader on Raspberry Pi. On this board, chip select may be labeled `SS` or `CS`.

```text
PN532 3.3V   -> Pi 3.3V
PN532 GND    -> Pi GND
PN532 SCK    -> GPIO11 / SCLK / pin 23
PN532 MISO   -> GPIO9  / MISO / pin 21
PN532 MOSI   -> GPIO10 / MOSI / pin 19
PN532 SS/CS  -> GPIO8  / CE0  / pin 24
```

Set the PN532 module's switches/jumpers to SPI mode. The exact switch positions depend on the board.

Enable SPI on the Pi:

```bash
sudo raspi-config
```

Then choose `Interface Options` -> `SPI` -> enable, and reboot.

## Physical Placement

- Put the PN532 directly under the "place character here" spot.
- Avoid metal between the tag and reader.
- Keep loose wiring strain-relieved inside the box.
- Keep the Pi accessible to adults, not freely removable by the kid.

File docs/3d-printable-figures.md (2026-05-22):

# Custom 3D Printable Figures

You can use generic toys, wooden tokens, peg dolls, printed tokens, or custom 3D printed figures. The goal is not a perfect collectible; it is a sturdy shape that a child can place on the box.

## Good Figure Constraints

- Chunky silhouette.
- Flat base.
- No thin arms, antennas, tails, horns, or spikes.
- No unsupported dramatic overhangs.
- Big enough to hold an NFC sticker under the base.
- Easy to recognize from across a room.

## NFC Base

For common round NFC stickers:

- Base diameter: 35-45 mm.
- Underside recess: 25-30 mm wide.
- Recess depth: about 0.5-1.0 mm, or enough to hide the sticker under felt/tape.
- Keep metal away from the tag.

If you do not want to model a recess yet, print a flat base and stick the tag under it with tape or felt.

This repo includes a reusable base at `cad/nfc-character-base.scad`. It renders a 42 mm rounded puck with a 25 mm sticker recess on the underside and a flat top pad for attaching custom figures. A ready-to-slice flat base is also available at [`../stl/nfc-character-base-flat.stl`](../stl/nfc-character-base-flat.stl).

### Included Base Specs

Source file: [`../cad/nfc-character-base.scad`](../cad/nfc-character-base.scad)

Units are millimeters.

| Feature | Spec |
| --- | ---: |
| Overall puck diameter | 42 mm |
| Main puck height | 8 mm |
| Total flat-base height including top pad | 8.8 mm |
| Outer edge bevel | 2 mm |
| Top figure landing pad diameter | 32 mm |
| Top figure landing pad height | 0.8 mm |
| Sticker target diameter | 25 mm |
| Sticker pocket diameter | 26.4 mm |
| Sticker pocket depth | 0.8 mm |
| Sticker pocket clearance | 1.4 mm total diameter clearance |
| Fingertip/notch relief | 7 mm diameter |
| Peg variant connector | 7.8 mm diameter x 3.2 mm high |
| Socket variant connector | 8.4 mm diameter x 3.4 mm deep |

The flat base is the public default. Use `peg` or `socket` only when you are designing both halves of the character connection.

If your NFC stickers are larger than 25 mm, edit `sticker_d` in `nfc-character-base.scad`, regenerate the STL, and print one test puck before merging it with a character.

Print orientation:

- Put the sticker recess on the print bed.
- Keep supports off.
- Check the slicer preview around the shallow pocket ceiling.
- After printing, place the sticker into the underside recess and cover it with thin felt, tape, or label paper.

Use the flat base for most generated figures:

```bash
cd cad
openscad -o build/nfc-character-base-flat.stl -D 'part="flat"' nfc-character-base.scad
```

Workflow:

1. Generate or model the character as a separate STL/3MF.
2. Make the character's feet/base flat.
3. Place it on top of `nfc-character-base-flat.stl` in Blender, Tinkercad, Bambu Studio, PrusaSlicer, or Cura.
4. Merge/group the meshes or let the slicer treat overlapping bodies as one print.
5. Print the combined figure.
6. Stick the NFC sticker into the underside recess.

There are also peg/socket variants:

- `nfc-character-base-peg.stl`: for figures modeled with a matching bottom socket.
- `nfc-character-base-socket.stl`: for figures modeled with a matching bottom peg.

The sticker belongs on the underside of the base, not buried high inside the figure. That keeps the tag close to the PN532 reader and makes scans more reliable.

## AI 3D Tool Workflow

Tools such as Tripo, Meshy, Blender add-ons, and other AI 3D generators can help make original toy-like figures. For printing, prefer STL or 3MF export when available.

Recommended flow:

1. Generate a simple character in Tripo, Meshy, or another AI 3D tool.
2. Export STL or 3MF for printing.
3. Open the file in Blender, Tinkercad, Bambu Studio, PrusaSlicer, or Cura.
4. Add or verify a flat base.
5. Add an underside NFC recess if you want one.
6. Check the slicer preview for fragile parts and unsupported areas.
7. Print in PLA.
8. Stick the NFC tag under the base.
9. Register the UID in the Magic Character Box admin UI.

If your tool offers export options such as flattening the bottom or centering the model pivot on the build plate, use them. Every character needs a stable base.

## Prompt Template

Use prompts that describe physical printability, not just visual style:

```text
A small friendly [character] mascot toy for a child's NFC story box.
Simple rounded shapes, chunky silhouette, flat circular base, no thin parts,
no fragile antennas, single solid object, designed for FDM 3D printing,
easy to recognize.
```

Examples:

```text
A small friendly rocket mascot toy for a child's NFC story box.
Simple rounded shapes, chunky silhouette, flat circular base, no thin parts,
single solid object, designed for FDM 3D printing.
```

```text
A small gentle dinosaur mascot toy for a child's NFC story box.
Chunky body, short legs, rounded head, flat oval base, no sharp teeth,
single solid object, designed for FDM 3D printing.
```

## Cleanup Checklist

Before printing:

- Model sits flat on the build plate.
- No tiny floating pieces.
- No ultra-thin features.
- Slicer preview shows closed geometry.
- The base is wide enough for the tag.
- The figure is large enough not to be a choking hazard for the intended child.
- You have the right to share any model files or photos you publish.

## Public Tutorial Photos

Use photos that make the build easier to understand: bases, stickers, reader placement, wiring, and finished figures.

## Useful References

Check your chosen 3D tool's export documentation before relying on a generated model. The stable project requirement is simple: end with a printable STL or 3MF that has a flat bottom and a base wide enough for the NFC sticker.

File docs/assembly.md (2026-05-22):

# Assembly Guide

This is the public build path for the first Magic Character Box prototype.

The goal is not a perfect toy on day one. The goal is a reliable magic moment:

```text
Place NFC character on the box -> Pi sees UID -> matching audio plays
```

If you want the shortest possible path, start with [quick-build.md](quick-build.md), then come back here for detail.

## Parts

For a fuller shopping/checkoff page, see [materials.md](materials.md).
If time is short before a birthday, use [birthday-weekend-build.md](birthday-weekend-build.md).

Required:

- Raspberry Pi Zero 2 W with soldered GPIO header.
- microSD card, 16 GB or larger.
- 5V 2A or better USB power supply.
- PN532 NFC reader, set to SPI mode.
- NTAG213/215/216 NFC stickers or fobs.
- MAX98357A I2S amp board.
- Small passive speaker, ideally 4-8 ohm.
- Jumper wires.
- Printed enclosure, cardboard box, project box, or other non-metal case.

Optional:

- M2.5 x 8 mm screws for the printed case.
- Hook-and-loop tape for the smaller sidecar enclosure.
- Thin felt or tape to cover NFC stickers in figure bases.
- USB keyboard/monitor for first Pi setup, or SSH.

## Helpful Photos

Use the wiring tables in [wiring.md](wiring.md) as the source of truth. Wire colors in photos are only examples.

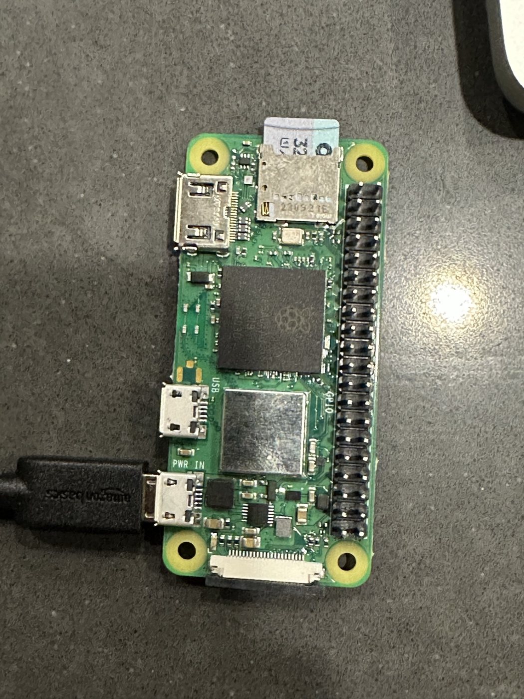
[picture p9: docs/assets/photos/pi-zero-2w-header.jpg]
Raspberry Pi Zero 2 W with GPIO header


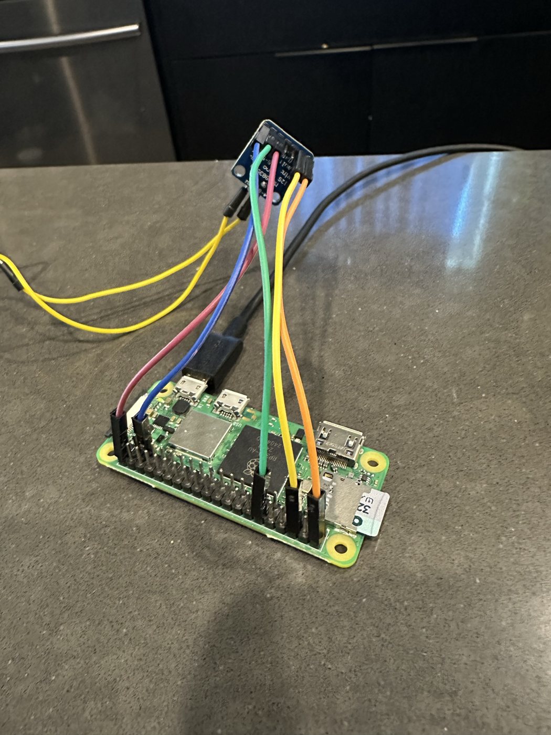
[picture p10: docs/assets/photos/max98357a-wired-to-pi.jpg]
Bench wiring with Pi and MAX98357A amp


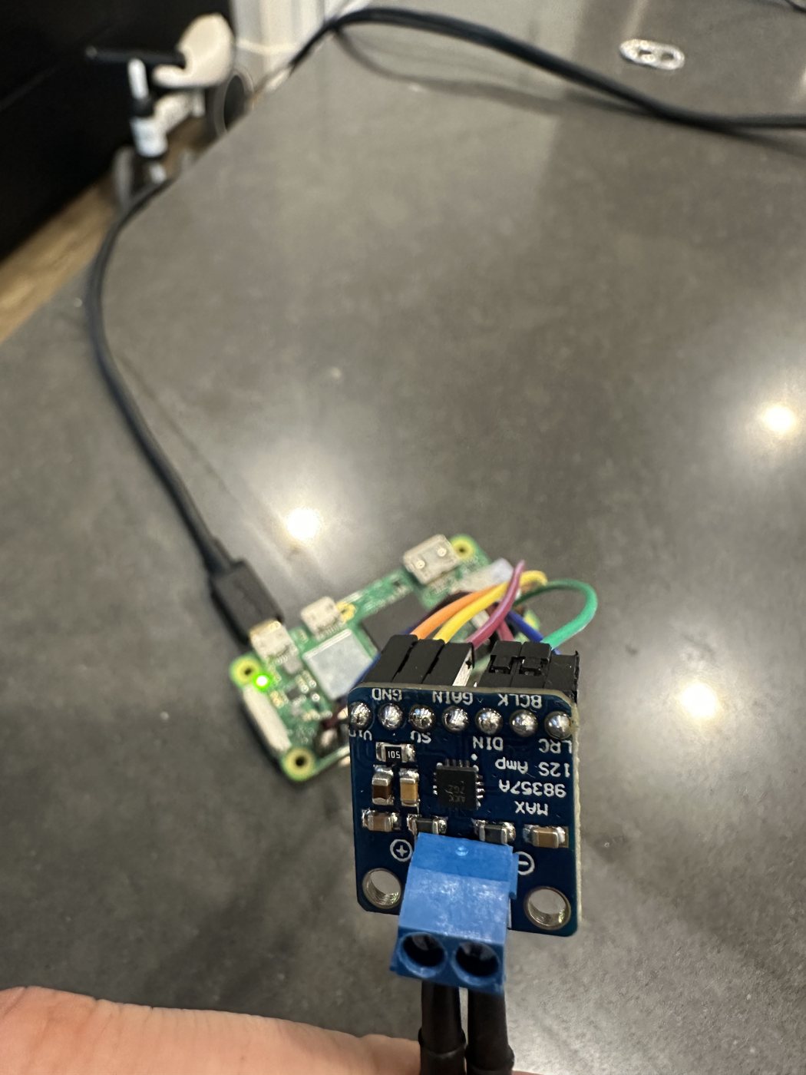
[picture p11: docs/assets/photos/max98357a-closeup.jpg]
MAX98357A amp closeup


## Print The Enclosure

The smaller enclosure is intended as a sidecar module: the Pi, PN532, and MAX98357A live in the printed case, then the case mounts to an existing passive speaker cabinet with hook-and-loop tape.

Ready-to-slice files:

- [`../stl/small-sidecar-enclosure-body.stl`](../stl/small-sidecar-enclosure-body.stl)
- [`../stl/small-sidecar-enclosure-lid.stl`](../stl/small-sidecar-enclosure-lid.stl)
- [`../stl/small-sidecar-enclosure-assembly.stl`](../stl/small-sidecar-enclosure-assembly.stl) for visual/reference use

Reusable figure base:

- [`../stl/nfc-character-base-flat.stl`](../stl/nfc-character-base-flat.stl)

Suggested print settings:

- PLA or PETG.
- 0.2 mm layer height.
- 3 walls.
- 4 top/bottom layers.
- 15-20% infill.
- Supports off for the body and NFC base.
- Check the lid in your slicer; support needs vary by printer.

Print orientation:

- Body: open side up.
- Lid: top side up.
- NFC character base: sticker recess down, top pad up. The shallow recess should bridge, but preview it in your slicer.

The parametric OpenSCAD source is in [`../cad/`](../cad/README.md).

## Wire The Hardware

Power the Pi off before wiring.

MAX98357A amp:

```text
MAX98357A VIN  -> Pi 5V, physical pin 2 or 4
MAX98357A GND  -> Pi GND
MAX98357A BCLK -> GPIO18, physical pin 12
MAX98357A LRC  -> GPIO19, physical pin 35
MAX98357A DIN  -> GPIO21, physical pin 40
MAX98357A SD   -> GPIO16, physical pin 36, optional but recommended
Speaker +      -> MAX98357A speaker +
Speaker -      -> MAX98357A speaker -
```

PN532 reader in SPI mode:

```text
PN532 VCC/3.3V -> Pi 3.3V, physical pin 1 or 17
PN532 GND      -> Pi GND
PN532 SCK      -> GPIO11, physical pin 23
PN532 MISO     -> GPIO9, physical pin 21
PN532 MOSI     -> GPIO10, physical pin 19
PN532 SS/CS    -> GPIO8, physical pin 24
```

Keep the PN532 under the top target area, with the antenna side facing the NFC tag. Keep metal and speaker magnets away from the reader when possible.

## Prepare The Pi

Install system packages and Python dependencies:

```bash
cd /home/pi/magic-character-box
./scripts/install_pi.sh
```

Enable SPI:

```bash
sudo raspi-config
```

Choose `Interface Options` -> `SPI` -> enable, then reboot.

For MAX98357A audio, add the overlay described in [wiring.md](wiring.md), then reboot before testing.

## Test In Small Steps

Start with mock mode:

```bash
python -m magic_box.app --nfc mock --dry-run-audio
```

Type:

```text
DINOSAUR
ROCKET
DAD
q
```

Then test real tag scanning:

```bash
python scripts/scan_tag.py --nfc pn532
```

Then test audio:

```bash
python -m magic_box.app --nfc mock
```

Only combine NFC and audio after both work separately.

## Register NFC Stickers

This project maps tag UIDs to audio folders. It does not write data to the NFC stickers.

Terminal registration:

```bash
python scripts/register_character.py --nfc pn532 --name Dinosaur --mode shuffle
```

Web registration:

```bash
python -m magic_box.admin --nfc pn532 --host 0.0.0.0 --port 8080
```

Open `http://<pi-hostname-or-ip>:8080`, scan the tag, name it, save it, then upload or record audio. The web UI creates the audio folder automatically. Audio uploads start as soon as files are selected from the file picker.

If the Scan button is disabled, the admin is probably running in mock/dev mode. Stop `magic-character-box-admin-dev`, stop the main app while registering tags, and start `magic-character-box-admin`.

More detail is in [rf-programming.md](rf-programming.md).

## Install The Services

After manual tests pass:

```bash
sudo cp systemd/magic-character-box.service /etc/systemd/system/
sudo cp systemd/magic-character-box-admin.service /etc/systemd/system/
sudo systemctl daemon-reload
```

For the MVP, use setup mode or kid playback mode, not both at once:

```bash
# Setup mode
sudo systemctl disable --now magic-character-box
sudo systemctl disable --now magic-character-box-admin-dev
sudo systemctl enable --now magic-character-box-admin

# Kid playback mode
sudo systemctl disable --now magic-character-box-admin
sudo systemctl enable --now magic-character-box
```

Watch logs:

```bash
journalctl -u magic-character-box -f
```

The admin page has no login, so keep it on a trusted home network.

If anything does not behave as expected, use [troubleshooting.md](troubleshooting.md).

## Close The Box

Before screwing the lid down:

- Confirm the speaker plays without harsh pops.
- Confirm the PN532 reads stickers through the lid.
- Confirm the Pi can still be powered and serviced by an adult.
- Strain-relieve jumper wires so a tug on the case does not pull pins loose.
- Keep loose batteries and exposed electronics away from kids.

For the sidecar enclosure, add hook-and-loop tape to the flat rear pad. Use the strap slots as a backup if adhesive tape is not enough.

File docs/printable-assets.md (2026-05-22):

# Printable Assets

These simple printables make the project feel like a gift instead of a loose electronics demo.

## Top Label

Print or hand-letter this on the lid:

```text
Place Character Here
```

Put the PN532 reader directly under this spot. Avoid metal foil labels.

## Gift Card

```text
Your Magic Character Box

These characters are empty right now.
You get to choose what powers they have.

Place one on top of the box.
The box will learn who it is.
Then we will teach it what to play.
```

## Mission Cards

```text
Mission 1: Wake The Box
Turn it on and hear the startup sound.
```

```text
Mission 2: Teach A Character
Scan a new character, name it, and add its first sound.
```

```text
Mission 3: Make A Family Token
Record a message from Dad, Mom, Grandma, Grandpa, or a friend.
```

```text
Mission 4: Build The Real Case
Decorate the box and make it yours.
```

## Token Labels

Useful first labels:

- Dinosaur
- Rocket
- Mystery
- Bedtime
- Dad
- Grandma
- Birthday
- Story

## NFC Sticker Note

If you print labels for the underside of figures, keep them thin. A thick stack of plastic, foam tape, or label material increases the distance between the NFC sticker and the reader.

## Open Source Photo Checklist

For public photos, use:

- Generic toy dinosaurs, rockets, robots, animals, or printed shapes.
- Your own labels and art.
- The printed NFC base from [3d-printable-figures.md](3d-printable-figures.md).
- No copyrighted music, private recordings, or branded toy characters in the repo.

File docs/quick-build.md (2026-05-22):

# Quick Build Path

This is the shortest path from parts on the table to a working Magic Character Box.

For deeper explanations, use [assembly.md](assembly.md), [wiring.md](wiring.md), and [web-admin.md](web-admin.md).

## 1. Buy Or Gather Parts

Minimum recommended build:

- Raspberry Pi Zero 2 W or Zero 2 WH.
- microSD card, 16 GB or larger.
- 5V USB power supply, 2A or better.
- PN532 NFC reader that supports SPI mode.
- NTAG213/215/216 NFC stickers or fobs.
- MAX98357A I2S amp board.
- 4-8 ohm passive speaker.
- 20+ female-to-female jumper wires.
- Printed sidecar enclosure or a cardboard/project box.

Use [materials.md](materials.md) as the shopping checklist.

## 2. Wire The Boards

Wire the Pi while it is powered off.

PN532 in SPI mode:

```text
PN532 VCC/3.3V -> Pi physical pin 1 or 17
PN532 GND      -> Pi GND
PN532 SCK      -> GPIO11 / physical pin 23
PN532 MISO     -> GPIO9  / physical pin 21
PN532 MOSI     -> GPIO10 / physical pin 19
PN532 SS/CS    -> GPIO8  / physical pin 24
```

MAX98357A:

```text
MAX98357A VIN  -> Pi 5V / physical pin 2 or 4
MAX98357A GND  -> Pi GND
MAX98357A BCLK -> GPIO18 / physical pin 12
MAX98357A LRC  -> GPIO19 / physical pin 35
MAX98357A DIN  -> GPIO21 / physical pin 40
MAX98357A SD   -> GPIO16 / physical pin 36
```

Full wiring notes are in [wiring.md](wiring.md).

## 3. Install The Software

On the Pi:

```bash
cd /home/pi/magic-character-box
./scripts/install_pi.sh
sudo raspi-config
```

Enable SPI in `raspi-config`, then reboot.

If using the MAX98357A, apply the audio setup from [wiring.md](wiring.md) and reboot again.

## 4. Prove Each Piece

Run these before closing the box:

```bash
python scripts/scan_tag.py --nfc pn532
```

```bash
python -m magic_box.app --nfc mock
```

The first proves NFC. The second proves audio playback.

## 5. Start The Dashboard

Install/start the services:

```bash
sudo cp systemd/magic-character-box.service /etc/systemd/system/
sudo cp systemd/magic-character-box-admin.service /etc/systemd/system/
sudo systemctl daemon-reload
sudo systemctl enable --now magic-character-box magic-character-box-admin
```

Open the dashboard from another device on the same Wi-Fi:

```text
http://<pi-hostname-or-ip>:8080
```

## 6. Teach The First Tag

1. Click `Setup scan`.
2. Put a blank NFC sticker on the reader.
3. Click `Scan`.
4. Name the character.
5. Click `Create character`.
6. Upload or record the first sound.
7. Click `Playback`.
8. Place the character on the box.

## 7. Before Handing It To A Kid

- Unplug and replug the Pi for a cold boot test.
- Confirm the box starts without SSH.
- Confirm the tags play the right sounds.
- Confirm the reader works through the lid.
- Confirm the Pi and wiring are not exposed.
- Keep the dashboard on your trusted home network only.

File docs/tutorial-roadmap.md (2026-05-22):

# Tutorial Roadmap

Build the box in stages. Each stage should produce a visible win before adding complexity.

## Part 1: The Ugly Magic Demo

Goal: prove the magic on a desk.

- Raspberry Pi Zero 2 W boots.
- Python app runs manually.
- Mock NFC mode works from the keyboard.
- PN532 can scan a tag.
- Local MP3 files play through any available audio output.
- Three starter identities work: Dinosaur, Rocket, and Dad Token.

Done when typing or scanning a tag changes the selected audio folder.

## Part 2: Make It Kid-Usable

Goal: make the box predictable after power-on.

- App starts on boot with systemd.
- Unknown tags produce a friendly sound or log entry.
- Repeat scans do not stutter.
- New tags can be registered with `scripts/register_character.py`.
- MAX98357A I2S audio is configured and tested.
- Volume is set to a safe default.

Done when a non-technical adult can power the box and swap characters without using SSH.

## Part 3: The Birthday Box

Goal: make the prototype feel like a gift.

- Follow [birthday-weekend-build.md](birthday-weekend-build.md) if time is short.
- Follow the assembly flow in [assembly.md](assembly.md).
- NFC reader is hidden under the top surface.
- Speaker is mounted behind a grille or holes.
- USB power remains adult-accessible.
- Wires are strain-relieved.
- Characters have hidden NFC stickers.
- Mission cards explain the game.
- Printable labels and mission-card copy are in [printable-assets.md](printable-assets.md).

Done when the child can place a character on the box and hear the right sound without seeing loose electronics.

## Part 4: Parent-Friendly Admin

Goal: make updates easy from another device on the home network.

- Local web page lists known characters.
- Parent can scan a new tag.
- Parent can name a character.
- Parent can upload or assign local audio.
- Parent can trigger test playback.
- Parent can use the last-seen tag to add a new character without copying a UID.
- Parent can download a backup of config and audio.
- Parent can read a simple event log instead of raw service logs.
- Optional voice-message flow supports family recordings.
- Printable-figure guidance helps builders make custom NFC characters.

Done when adding a new character no longer requires editing JSON by hand.

## Future: Bluetooth Receiver Mode

Goal: let a parent stream audio from a phone or laptop to the Magic Character Box like a Bluetooth speaker, while keeping NFC playback as the main child-facing experience.

- Add a dashboard control to make the Pi discoverable for a short window, such as 3 minutes.
- Pair a phone/laptop to the Pi as an audio source.
- Route incoming Bluetooth audio through the Pi's normal PipeWire/Pulse output, then through the MAX98357A speaker.
- Show connected source device status in the admin page.
- Add a `Disconnect` button for the current source.
- Decide how NFC playback behaves while Bluetooth audio is streaming: pause/stop NFC playback, or make Bluetooth receiver mode a separate parent-controlled mode.
- Keep the Pi non-discoverable by default.

This is distinct from the existing experimental Bluetooth panel, which is for sending Pi audio out to an external Bluetooth speaker. Receiver mode is the reverse path: phone or laptop audio into the box.

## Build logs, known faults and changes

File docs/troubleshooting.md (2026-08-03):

# Troubleshooting

Start with the dashboard's `Device details` -> `Box tools` -> `Test box` button. It checks the chime, NFC readiness, audio command, service mode, and free storage.

## Dashboard Scan Button Is Disabled

Likely cause: the admin is running in mock/dev mode, or the playback service is using the PN532.

Try:

1. Open `http://<pi-hostname-or-ip>:8080`.
2. Click `Setup scan`.
3. Refresh the page.
4. Try `Scan` again.

From SSH:

```bash
systemctl status magic-character-box-admin
systemctl status magic-character-box
```

The real admin service should include `--nfc pn532`. If you see `--nfc mock`, stop the dev admin and start the real admin.

## NFC Tag Does Not Read

Check:

- PN532 switch/jumper is set to SPI mode.
- SPI is enabled in `sudo raspi-config`.
- PN532 `VCC` is on Pi `3.3V`, not 5V unless your board specifically requires 5V-tolerant power.
- `SCK`, `MISO`, `MOSI`, and `SS/CS` match [wiring.md](wiring.md).
- The tag is close to the antenna and not blocked by metal.
- The reader is not too far below the lid.

Test directly:

```bash
python scripts/scan_tag.py --nfc pn532
```

If the dashboard shows a `Last seen tag`, the reader worked at least once. Use `Use this tag` in Teach Mode to avoid copying the UID manually.

## No Audio

Check:

- Speaker is wired to the MAX98357A speaker output, not to Pi GPIO.
- MAX98357A `VIN` is on Pi 5V.
- `BCLK`, `LRC`, and `DIN` match [wiring.md](wiring.md).
- The Pi audio overlay is configured and the Pi has rebooted.
- `mpg123` is installed.
- Dashboard volume is not too low.

Quick test:

```bash
mpg123 -q -o alsa -a plughw:CARD=MAX98357A,DEV=0 --rate 48000 --stereo -e s16 audio/system/startup-chime.mp3
```

If you hear clicks but no sound, recheck `BCLK`, `LRC`, and `DIN`; swapped clock pins are a common mistake.

## Pops Or Clicks

The recommended build uses three layers of protection:

- MAX98357A `SD` wired to `GPIO16 / physical pin 36`.
- One continuous `aplay` sink on `plughw:CARD=MAX98357A,DEV=0`, fixed at 48 kHz stereo S16.
- Lower `MAGIC_BOX_MAX_OUTPUT_VOLUME` below its default `100` only when a known speaker, power, or wiring path needs a hardware-specific safety ceiling.

Uploaded and recorded files are also prepared with short fades and loudness normalization when `ffmpeg` is installed.

See [web-admin.md](web-admin.md#reducing-speaker-pops) and [wiring.md](wiring.md).

## Crackly Or Overdriven Audio

If the speaker sounds crunchy while full audio still plays, lower the shared software volume first:

```bash
cd /home/pi/magic-character-box
.venv/bin/python - <<'PY'
from pathlib import Path
from magic_box.volume import VolumeControl

VolumeControl(Path("config/volume.json")).set(55)
PY
sudo systemctl restart magic-character-box magic-character-box-admin
```

If it still crackles at normal room volume, keep the dashboard volume where it is and lower `MAGIC_BOX_MAX_OUTPUT_VOLUME` in the systemd service override or service file. Values around `65` to `75` are usually safer for a small MAX98357A/passive-speaker path than raw full-scale output.

If volume changes do not affect the crackle, suspect the output path or hardware instead. Player services should use `MAGIC_BOX_AUDIO_BACKEND=continuous-pcm`, an `mpg123 -s --rate 48000 --stereo -e s16` decoder, `MAGIC_BOX_AMP_MUTE_BETWEEN_TRACKS=0`, and one `aplay` sink fixed to `plughw:CARD=MAX98357A,DEV=0` at 48 kHz stereo S16. Verify both `mpg123` and the `alsa-utils` package that supplies `aplay` are installed. The admin services intentionally stay on one-shot playback and should not run alongside finished-box player mode. If a deployed box shows `mpg123-remote`, `dmix`, `-e s32`, Pulse, per-track amp muting, or an active `magic-character-box-audio-keeper.service`, restore the player service and restart it. Between clips, exactly one `aplay` process should hold the ALSA PCM device; idle zero PCM must not count as audible playback.

## Browser Recording Does Not Work

Browsers require a secure origin for microphone access.

Use one of:

- Upload an existing voice memo from the character's `Add audio` panel.
- `http://localhost` while developing on the same machine.
- A temporary HTTPS tunnel to the guest-only recorder for remote family.

The dashboard hides the browser `Record` controls when the page is not secure enough for microphone access.

See [web-admin.md](web-admin.md#guest-recording-links).

## Uploaded Audio Is Not Playable

MP3 files play directly. Other formats need `ffmpeg` conversion.

Install:

```bash
sudo apt install -y ffmpeg
```

Then upload again. The dashboard message should say the file was prepared.

## Wrong Character Plays

Open the dashboard and check the character's UID badges. If you reused a tag or accidentally registered the wrong sticker:

1. Open `Character settings`.
2. Delete the wrong character mapping.
3. Scan the tag again in Teach Mode.
4. Name it and add audio.

Deleting a character mapping does not delete its audio folder.

## Box Does Not Start After Reboot

Check services:

```bash
systemctl is-active magic-character-box
systemctl is-active magic-character-box-admin
journalctl -u magic-character-box -n 80 --no-pager
```

Common causes:

- Pi is still booting.
- Weak USB power supply.
- Missing Python virtual environment.
- SPI or I2S setup changed before reboot.
- Audio device is unavailable because the MAX98357A ALSA card is missing or the service is pointing at the wrong output path.

The player waits up to 60 seconds for unprivileged GPIO and SPI access before
starting. Check that readiness path as the actual service user:

```bash
ls -l /dev/gpiomem /dev/spidev0.0
id -nG pi
sudo -u pi /home/pi/magic-character-box/.venv/bin/python \
  -m magic_box.hardware_ready --timeout 0
```

Both device nodes must be readable and writable by `pi`; its groups should
include `gpio` and `spi`. If an older deployment logs `No access to /dev/mem`
only during early boot, restore the current player service before debugging the
PN532 wiring. That RPi.GPIO message can mean `/dev/gpiomem` existed before udev
finished applying its group permissions.

## Running Out Of Space

The dashboard `Test box` result includes free storage. You can also run:

```bash
df -h /
du -h -d 2 audio | sort -h
```

Use `Download backup` before deleting large local clips.

## I Need To Recover A Build

1. Download a backup from the dashboard if it still opens.
2. Copy off `/home/pi/magic-character-box/config/` and `/home/pi/magic-character-box/audio/`.
3. Reinstall the repo.
4. Restore `config/characters.json` and the `audio/` folders.
5. Restart services.

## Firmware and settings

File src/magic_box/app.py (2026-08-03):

"""Application loop for the Magic Character Box."""

from __future__ import annotations

import argparse
from dataclasses import dataclass
import logging
import os
from pathlib import Path
import signal
import time
from typing import Sequence

from .amp import create_amp_gate
from .audio import AudioInitializationError, AudioPlayer, AudioRuntimeError
from .config import CharacterConfig, ConfigError, project_root_for_config
from .control import consume_stop_request, control_file_for_config
from .nfc import NFCError, StopRequested, create_reader
from .player_load import PlayerLoadBridge, PlayerLoadError
from .runtime_state import append_event, record_tag, state_file_for_config
from .volume import (
    DEFAULT_MAX_OUTPUT_VOLUME_PERCENT,
    DEFAULT_VOLUME_PERCENT,
    VolumeControl,
    apply_pipewire_volume,
    effective_output_volume,
    volume_file_for_config,
)


LOGGER = logging.getLogger(__name__)
DEFAULT_STARTUP_SOUND = "audio/system/startup-chime.mp3"
DEFAULT_UNKNOWN_SOUND = "audio/system/unknown-tag.mp3"
GPIO_NFC_BACKENDS = frozenset({"pn532", "pn532-spi", "spi", "pn532-ndef"})


class _ServiceStopRequested(Exception):
    """Raised by SIGTERM so the player can close its children in order."""


def _handle_service_stop(_signum: int, _frame: object) -> None:
    raise _ServiceStopRequested


class _DeferredServiceStopHandler:
    """Defer SIGTERM until audio construction has a closeable owner."""

    def __init__(self) -> None:
        self.requested = False
        self._armed = False

    def __call__(self, signum: int, frame: object) -> None:
        self.requested = True
        if self._armed:
            _handle_service_stop(signum, frame)

    def arm(self) -> None:
        self._armed = True
        if self.requested:
            raise _ServiceStopRequested

    def defer(self) -> None:
        self._armed = False


def _optional_int(value: str | None) -> int | None:
    if value is None or not value.strip():
        return None
    return int(value)


def _env_flag(name: str, default: bool = False) -> bool:
    value = os.getenv(name)
    if value is None:
        return default
    return value.strip().lower() in {"1", "true", "yes", "on"}


def _configure_gpio_working_directory(
    config_path: Path,
    *,
    nfc_backend: str,
    amp_gpio: int | None,
) -> None:
    """Keep lgpio notification FIFOs beside persistent runtime config."""

    if nfc_backend not in GPIO_NFC_BACKENDS and amp_gpio is None:
        return
    os.environ.setdefault("LG_WD", str(config_path.expanduser().resolve().parent))


def build_parser() -> argparse.ArgumentParser:
    parser = argparse.ArgumentParser(description="Run the Magic Character Box")
    parser.add_argument(
        "--config",
        default=os.getenv("MAGIC_BOX_CONFIG", "config/characters.json"),
        help="Path to characters.json",
    )
    parser.add_argument(
        "--nfc",
        default=os.getenv("MAGIC_BOX_NFC", "mock"),
        choices=[
            "mock",
            "keyboard",
            "dev",
            "file",
            "trigger-file",
            "queue",
            "pn532",
            "pn532-spi",
            "spi",
            "pn532-ndef",
        ],
        help="NFC reader backend",
    )
    parser.add_argument(
        "--audio-command",
        default=os.getenv("MAGIC_BOX_AUDIO_CMD", "mpg123 -q"),
        help="Command used to play one audio file",
    )
    parser.add_argument(
        "--audio-backend",
        choices=["subprocess", "mpg123-remote", "continuous-pcm"],
        default=os.getenv("MAGIC_BOX_AUDIO_BACKEND", "subprocess"),
        help="Use one-shot playback, mpg123 remote mode, or one continuous direct PCM sink.",
    )
    parser.add_argument(
        "--audio-sink-command",
        default=os.getenv("MAGIC_BOX_AUDIO_SINK_CMD", "aplay -q"),
        help="Long-lived raw PCM sink command used by the continuous-pcm backend.",
    )
    parser.add_argument(
        "--audio-warmup-file",
        default=os.getenv("MAGIC_BOX_AUDIO_WARMUP_FILE"),
        help="Optional silent MP3 to load at startup when using mpg123-remote.",
    )
    parser.add_argument(
        "--startup-sound",
        default=os.getenv("MAGIC_BOX_STARTUP_SOUND", DEFAULT_STARTUP_SOUND),
        help="Optional sound to play once when the app starts. Set to an empty string to disable.",
    )
    parser.add_argument(
        "--unknown-sound",
        default=os.getenv("MAGIC_BOX_UNKNOWN_SOUND", DEFAULT_UNKNOWN_SOUND),
        help="Optional sound to play when an unregistered tag is found. Set to an empty string to disable.",
    )
    parser.add_argument(
        "--dry-run-audio",
        action="store_true",
        default=os.getenv("MAGIC_BOX_DRY_RUN_AUDIO", "").lower() in {"1", "true", "yes"},
        help="Log selected audio files without launching a player",
    )
    parser.add_argument(
        "--volume-file",
        default=os.getenv("MAGIC_BOX_VOLUME_FILE"),
        help="Path to shared software volume JSON. Defaults to config/volume.json beside characters.json.",
    )
    parser.add_argument(
        "--control-file",
        default=os.getenv("MAGIC_BOX_CONTROL_FILE"),
        help="Path to shared admin control JSON. Defaults to config/control.json beside characters.json.",
    )
    parser.add_argument(
        "--state-file",
        default=os.getenv("MAGIC_BOX_STATE_FILE"),
        help="Path to shared runtime state JSON. Defaults to config/device_state.json beside characters.json.",
    )
    parser.add_argument(
        "--default-volume",
        type=int,
        default=int(os.getenv("MAGIC_BOX_DEFAULT_VOLUME", str(DEFAULT_VOLUME_PERCENT))),
        help="Default software volume percentage when no volume file exists.",
    )
    parser.add_argument(
        "--max-output-volume",
        type=int,
        default=int(os.getenv("MAGIC_BOX_MAX_OUTPUT_VOLUME", str(DEFAULT_MAX_OUTPUT_VOLUME_PERCENT))),
        help="Maximum output volume percentage after applying the user-facing volume.",
    )
    parser.add_argument(
        "--amp-sd-gpio",
        type=int,
        default=_optional_int(os.getenv("MAGIC_BOX_AMP_SD_GPIO")),
        help="Optional BCM GPIO connected to MAX98357A SD/shutdown. Example: GPIO16 is physical pin 36.",
    )
    parser.add_argument(
        "--amp-unmute-delay",
        type=float,
        default=float(os.getenv("MAGIC_BOX_AMP_UNMUTE_DELAY", "0.12")),
        help="Seconds to wait after starting playback before enabling the amp.",
    )
    parser.add_argument(
        "--amp-mute-delay",
        type=float,
        default=float(os.getenv("MAGIC_BOX_AMP_MUTE_DELAY", "0.05")),
        help="Seconds to wait after playback exits before muting the amp.",
    )
    parser.add_argument(
        "--amp-mute-between-tracks",
        action="store_true",
        default=_env_flag("MAGIC_BOX_AMP_MUTE_BETWEEN_TRACKS"),
        help="Power-cycle the amp around each clip. Usually off because SD wake can pop.",
    )
    parser.add_argument(
        "--cooldown",
        type=float,
        default=float(os.getenv("MAGIC_BOX_COOLDOWN", "3.0")),
        help="Legacy repeat cooldown in seconds. Tag-present repeats are ignored until removal.",
    )
    parser.add_argument(
        "--removal-debounce",
        type=float,
        default=float(os.getenv("MAGIC_BOX_REMOVAL_DEBOUNCE", "0.75")),
        help="Seconds a tag must be absent before the same UID can trigger again",
    )
    parser.add_argument(
        "--poll-interval",
        type=float,
        default=float(os.getenv("MAGIC_BOX_POLL_INTERVAL", "0.2")),
        help="Seconds to sleep when no tag is present",
    )
    parser.add_argument(
        "--log-level",
        default=os.getenv("MAGIC_BOX_LOG_LEVEL", "INFO"),
        help="Python logging level",
    )
    parser.add_argument(
        "--transactional-config",
        action="store_true",
        default=_env_flag("MAGIC_BOX_TRANSACTIONAL_CONFIG"),
        help=(
            "Opt in to request/ack config activation and block ordinary mtime reloads. "
            "Maker mode leaves this off."
        ),
    )
    return parser


def main(argv: Sequence[str] | None = None) -> int:
    args = build_parser().parse_args(argv)
    logging.basicConfig(
        level=getattr(logging, args.log_level.upper(), logging.INFO),
        format="%(asctime)s %(levelname)s %(name)s: %(message)s",
    )

    config_path = Path(args.config)
    try:
        config = CharacterConfig.load(config_path)
    except ConfigError as exc:
        LOGGER.error("%s", exc)
        return 2
    _configure_gpio_working_directory(
        config.path,
        nfc_backend=args.nfc,
        amp_gpio=args.amp_sd_gpio,
    )
    config_mtime = _config_mtime(config.path)
    player_load_bridge: PlayerLoadBridge | None = None
    if args.transactional_config:
        try:
            player_load_bridge = PlayerLoadBridge(config)
        except PlayerLoadError as exc:
            LOGGER.error("Transactional config setup is unsafe: %s", exc)
            return 2

    try:
        reader = create_reader(args.nfc, config_path=config.path)
    except NFCError as exc:
        LOGGER.error("%s", exc)
        return 2

    volume_path = Path(args.volume_file).expanduser().resolve() if args.volume_file else volume_file_for_config(config_path)
    control_path = Path(args.control_file).expanduser().resolve() if args.control_file else control_file_for_config(config_path)
    state_path = Path(args.state_file).expanduser().resolve() if args.state_file else state_file_for_config(config_path)
    startup_sound = _resolve_optional_audio_path(config_path, args.startup_sound)
    unknown_sound = _resolve_optional_audio_path(config_path, args.unknown_sound)
    volume = VolumeControl(volume_path, default_percent=args.default_volume)
    apply_pipewire_volume(effective_output_volume(volume.get(), args.max_output_volume))
    amp_gate = create_amp_gate(args.amp_sd_gpio)
    previous_sigterm = signal.getsignal(signal.SIGTERM)
    stop_handler = _DeferredServiceStopHandler()
    signal.signal(signal.SIGTERM, stop_handler)
    player: AudioPlayer | None = None
    try:
        player = AudioPlayer(
            command=args.audio_command,
            dry_run=args.dry_run_audio,
            volume_getter=volume.get,
            max_output_percent=args.max_output_volume,
            amp_gate=amp_gate,
            amp_unmute_delay=args.amp_unmute_delay,
            amp_mute_delay=args.amp_mute_delay,
            mute_between_tracks=args.amp_mute_between_tracks,
            use_mpg123_remote=args.audio_backend == "mpg123-remote",
            use_continuous_pcm=args.audio_backend == "continuous-pcm",
            sink_command=args.audio_sink_command,
            warmup_file=Path(args.audio_warmup_file).expanduser().resolve() if args.audio_warmup_file else None,
        )
        stop_handler.arm()
        LOGGER.info("Magic Character Box ready using %s NFC", args.nfc)
        _safe_append_event(state_path, "system", "Box started.")
        _play_system_sound(player, startup_sound, "startup")
        tag_state = _TagPlaybackState()
        while True:
            player.raise_if_unhealthy()
            if player_load_bridge is not None:
                config_reloaded = player_load_bridge.poll()
                config = player_load_bridge.config
            else:
                config, config_mtime, config_reloaded = _reload_config_if_changed(
                    config_path,
                    config,
                    config_mtime,
                )
            if config_reloaded:
                if player_load_bridge is not None:
                    LOGGER.info("Loaded requested character config activation")
                else:
                    LOGGER.info("Reloaded character config after sync update")

            if consume_stop_request(control_path):
                LOGGER.info("Admin stop audio requested")
                player.stop_current()
                _safe_append_event(state_path, "audio", "Audio stopped from dashboard.")

            try:
                uid = reader.read_uid()
            except StopRequested:
                LOGGER.info("Stop requested")
                return 0
            except NFCError as exc:
                LOGGER.warning("%s", exc)
                time.sleep(max(args.poll_interval, 1.0))
                continue

            now = time.monotonic()
            if not tag_state.should_handle(
                uid,
                now=now,
                removal_debounce=args.removal_debounce,
                active_audio_playing=player.is_playing(),
            ):
                if not uid:
                    time.sleep(args.poll_interval)
                else:
                    LOGGER.debug("Ignoring still-present or self-interrupting tag %s", uid)
                continue

            character = config.lookup(uid)
            if character is None:
                invalidate_cached_identity = getattr(reader, "invalidate_cached_identity", None)
                if callable(invalidate_cached_identity):
                    invalidate_cached_identity(uid)
                LOGGER.warning("Unknown tag %s", uid)
                _safe_record_tag(state_path, uid, known=False, source="playback")
                if _play_system_sound(player, unknown_sound, "unknown tag"):
                    tag_state.note_audio_started(uid)
                continue

            LOGGER.info("Playing %s (%s)", character.name, character.uid)
            _safe_record_tag(state_path, uid, known=True, character_name=character.name, source="playback")
            if player.play_folder(character.folder, character.mode):
                _safe_append_event(
                    state_path,
                    "audio",
                    f"{character.name} playback requested.",
                    uid=uid,
                    character_name=character.name,
                )
                tag_state.note_audio_started(uid)
            else:
                _safe_append_event(
                    state_path,
                    "audio",
                    "Selected audio could not start.",
                    uid=uid,
                    character_name=character.name,
                )
    except AudioInitializationError as exc:
        if stop_handler.requested:
            LOGGER.info("Service stop requested during audio initialization")
            return 0
        LOGGER.error("Audio initialization failed: %s", exc)
        return 2
    except AudioRuntimeError as exc:
        LOGGER.error("Audio backend failed: %s", exc)
        return 3
    except _ServiceStopRequested:
        LOGGER.info("Service stop requested")
        return 0
    except KeyboardInterrupt:
        LOGGER.info("Interrupted")
        return 130
    finally:
        stop_handler.defer()
        try:
            if player is None:
                amp_gate.close()
            else:
                player.close()
        finally:
            signal.signal(signal.SIGTERM, previous_sigterm)


def _resolve_optional_audio_path(config_path: Path, value: str | None) -> Path | None:
    if value is None or not value.strip():
        return None

    path = Path(value).expanduser()
    if not path.is_absolute():
        path = project_root_for_config(config_path) / path
    return path.resolve()


@dataclass
class _TagPlaybackState:
    active_uid: str | None = None
    absent_since: float | None = None
    playing_uid: str | None = None

    def should_handle(
        self,
        uid: str | None,
        *,
        now: float,
        removal_debounce: float,
        active_audio_playing: bool,
    ) -> bool:
        if not uid:
            if self.active_uid is not None:
                if self.absent_since is None:
                    self.absent_since = now
                elif now - self.absent_since >= removal_debounce:
                    LOGGER.debug("Tag %s removed", self.active_uid)
                    self.active_uid = None
                    self.absent_since = None
            return False

        self.absent_since = None
        if uid == self.active_uid:
            return False
        if uid == self.playing_uid and active_audio_playing:
            self.active_uid = uid
            return False

        self.active_uid = uid
        return True

    def note_audio_started(self, uid: str) -> None:
        self.playing_uid = uid


def _play_system_sound(player: AudioPlayer, path: Path | None, label: str) -> bool:
    if path is None:
        return False
    if not path.exists():
        LOGGER.info("Skipping %s sound; file not found: %s", label, path)
        return False
    player.stop_current()
    return player.play_file(path)


def _config_mtime(path: Path) -> float | None:
    try:
        return path.expanduser().resolve().stat().st_mtime
    except OSError:
        return None


def _reload_config_if_changed(
    config_path: Path,
    current_config: CharacterConfig,
    last_mtime: float | None,
) -> tuple[CharacterConfig, float | None, bool]:
    current_mtime = _config_mtime(config_path)
    if current_mtime is None or current_mtime == last_mtime:
        return current_config, last_mtime, False

    try:
        return CharacterConfig.load(config_path), current_mtime, True
    except ConfigError as exc:
        LOGGER.warning("Could not reload changed character config: %s", exc)
        return current_config, current_mtime, False


def _safe_record_tag(
    state_path: Path,
    uid: str,
    *,
    known: bool,
    character_name: str | None = None,
    source: str,
) -> None:
    try:
        record_tag(state_path, uid, known=known, character_name=character_name, source=source)
    except OSError as exc:
        LOGGER.warning("Could not write last-seen tag state: %s", exc)


def _safe_append_event(
    state_path: Path,
    event_type: str,
    message: str,
    *,
    uid: str | None = None,
    character_name: str | None = None,
) -> None:
    try:
        append_event(state_path, event_type, message, uid=uid, character_name=character_name)
    except OSError as exc:
        LOGGER.warning("Could not write device event: %s", exc)


if __name__ == "__main__":
    raise SystemExit(main())

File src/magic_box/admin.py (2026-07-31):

"""Local web admin UI for the Magic Character Box."""

from __future__ import annotations

import argparse
from dataclasses import dataclass
from datetime import datetime
from io import BytesIO
import logging
import os
from pathlib import Path
import secrets
import shlex
import shutil
import subprocess
import threading
import time
from typing import Any, Sequence
from zipfile import ZIP_DEFLATED, ZipFile

from flask import Flask, flash, jsonify, make_response, redirect, render_template, request, send_file, url_for
from werkzeug.datastructures import FileStorage
from werkzeug.middleware.proxy_fix import ProxyFix
from werkzeug.utils import secure_filename

from .amp import create_amp_gate
from .audio_prep import prepare_playable_mp3
from .audio import AudioPlayer
from .bluetooth import BluetoothController
from .config import (
    VALID_MODES,
    folder_for_config,
    folder_from_config_value,
    load_raw_config,
    normalize_uid,
    project_root_for_config,
    slugify_name,
    unique_character_folder,
    write_raw_config,
)
from .control import control_file_for_config, request_stop
from .fake_tags import queue_fake_tag, trigger_file_from_env
from .guest_links import (
    GuestLink,
    GuestLinkError,
    create_guest_link as make_guest_link,
    get_guest_link,
    guest_links_file_for_config,
    load_guest_links,
    revoke_guest_link,
)
from .nfc import NFCError, NFCReader, StopRequested, create_reader
from .qr_codes import QRCodeError, make_qr_svg
from .runtime_state import append_event, load_state, record_tag, state_file_for_config
from .story_stickers import (
    StorySticker,
    StoryStickerError,
    bind_story_sticker_uid,
    claim_story_sticker,
    create_story_sticker,
    get_story_sticker,
    load_story_stickers,
    story_stickers_file_for_config,
)
from .system_mode import ServiceModeController
from .volume import (
    DEFAULT_MAX_OUTPUT_VOLUME_PERCENT,
    DEFAULT_VOLUME_PERCENT,
    VOLUME_STEP_PERCENT,
    VolumeControl,
    apply_pipewire_volume,
    effective_output_volume,
    volume_file_for_config,
)
from .wifi import WifiController


LOGGER = logging.getLogger(__name__)
UPLOAD_EXTENSIONS = {".mp3", ".wav", ".m4a", ".ogg", ".flac", ".webm", ".mp4"}
PLAYABLE_EXTENSIONS = {".mp3"}
CAPTIVE_PORTAL_PROBE_PATHS = (
    "/hotspot-detect.html",
    "/library/test/success.html",
    "/generate_204",
    "/gen_204",
    "/connecttest.txt",
    "/ncsi.txt",
    "/canonical.html",
    "/success.txt",
)
DEFAULT_RECOVERY_HOSTS = "10.42.0.1,storydock.setup,storydock.local,storydock"


@dataclass(frozen=True)
class AdminCharacter:
    uid: str
    uids: list[str]
    name: str
    folder: Path
    folder_label: str
    mode: str
    playable_files: list[Path]
    other_files: list[Path]


@dataclass(frozen=True)
class SaveResult:
    filename: str
    playable: bool
    converted: bool
    message: str


@dataclass(frozen=True)
class GuestLinkView:
    token: str
    uid: str
    label: str
    character_name: str
    path: str
    url: str
    qr_url: str
    access_label: str
    access_hint: str
    is_secure: bool
    is_public_hint: bool
    expires_label: str
    expired: bool


@dataclass(frozen=True)
class StoryStickerView:
    token: str
    uid: str
    support_code: str
    name: str
    folder_label: str
    playable_count: int
    status_label: str
    path: str
    url: str
    qr_url: str
    can_play_on_box: bool


class ReaderState:
    """Lazily create the PN532 reader only when the browser actually scans."""

    def __init__(self, backend: str) -> None:
        self.backend = backend
        self.normalized_backend = backend.strip().lower()
        self.reader: NFCReader | None = None

    def browser_scan_error(self) -> str | None:
        if self.normalized_backend in {"mock", "keyboard", "dev"}:
            return "Mock mode cannot scan from the browser; type the UID manually."
        return None

    def get_reader(self) -> NFCReader:
        if self.reader is None:
            self.reader = create_reader(self.backend)
        return self.reader

    def reset(self) -> None:
        self.reader = None


def create_app(
    config_path: str | Path = "config/characters.json",
    nfc_backend: str = "mock",
    audio_command: str = "mpg123 -q",
    dry_run_audio: bool = False,
    volume_file: str | Path | None = None,
    default_volume: int = DEFAULT_VOLUME_PERCENT,
    max_output_volume: int = DEFAULT_MAX_OUTPUT_VOLUME_PERCENT,
    amp_sd_gpio: int | None = None,
    amp_unmute_delay: float = 0.12,
    amp_mute_delay: float = 0.05,
    amp_mute_between_tracks: bool = False,
    audio_backend: str = "subprocess",
    audio_warmup_file: str | Path | None = None,
    control_file: str | Path | None = None,
    guest_links_file: str | Path | None = None,
    story_stickers_file: str | Path | None = None,
    state_file: str | Path | None = None,
    guest_only: bool = False,
    bluetooth_controller: BluetoothController | None = None,
    wifi_controller: WifiController | None = None,
    mode_controller: ServiceModeController | None = None,
) -> Flask:
    app = Flask(__name__)
    app.secret_key = os.getenv("MAGIC_BOX_ADMIN_SECRET", "magic-character-box-local-dev")
    recovery_csrf_token = secrets.token_urlsafe(32)
    app.config["STORY_DOCK_RECOVERY_CSRF_TOKEN"] = recovery_csrf_token
    if _env_flag("MAGIC_BOX_TRUST_PROXY_HEADERS"):
        app.wsgi_app = ProxyFix(app.wsgi_app, x_for=1, x_proto=1, x_host=1)
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

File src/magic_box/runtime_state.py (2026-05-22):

"""Small shared runtime state for the playback service and admin UI."""

from __future__ import annotations

from datetime import datetime, timezone
import json
import logging
import os
from pathlib import Path
from typing import Any

from .config import normalize_uid


LOGGER = logging.getLogger(__name__)
MAX_EVENTS = 80


def state_file_for_config(config_path: str | Path) -> Path:
    """Default to a device state file beside characters.json."""

    return Path(config_path).expanduser().resolve().parent / "device_state.json"


def load_state(path: str | Path) -> dict[str, Any]:
    state_path = Path(path).expanduser().resolve()
    try:
        raw = state_path.read_text(encoding="utf-8")
    except FileNotFoundError:
        return _empty_state()
    except OSError as exc:
        LOGGER.warning("Could not read device state %s: %s", state_path, exc)
        return _empty_state()

    try:
        data = json.loads(raw)
    except json.JSONDecodeError:
        LOGGER.warning("Ignoring invalid device state file %s", state_path)
        return _empty_state()

    if not isinstance(data, dict):
        return _empty_state()
    last_tag = data.get("last_tag")
    events = data.get("events")
    return {
        "last_tag": last_tag if isinstance(last_tag, dict) else None,
        "events": events if isinstance(events, list) else [],
    }


def record_tag(
    path: str | Path,
    uid: str,
    *,
    known: bool,
    character_name: str | None = None,
    source: str = "reader",
) -> dict[str, Any]:
    normalized_uid = normalize_uid(uid)
    label = character_name or "Unknown tag"
    message = f"{label} {'seen' if known else 'found'} ({normalized_uid})."
    tag = {
        "uid": normalized_uid,
        "known": bool(known),
        "character_name": character_name,
        "source": source,
        "seen_at": _now_iso(),
    }
    data = load_state(path)
    data["last_tag"] = tag
    data["events"] = [_event("tag", message, uid=normalized_uid, character_name=character_name), *data["events"]][
        :MAX_EVENTS
    ]
    write_state(path, data)
    return tag


def append_event(
    path: str | Path,
    event_type: str,
    message: str,
    *,
    uid: str | None = None,
    character_name: str | None = None,
    level: str = "info",
) -> dict[str, Any]:
    event = _event(
        event_type,
        message,
        uid=normalize_uid(uid) if uid else None,
        character_name=character_name,
        level=level,
    )
    data = load_state(path)
    data["events"] = [event, *data["events"]][:MAX_EVENTS]
    write_state(path, data)
    return event


def write_state(path: str | Path, data: dict[str, Any]) -> None:
    state_path = Path(path).expanduser().resolve()
    state_path.parent.mkdir(parents=True, exist_ok=True)
    payload = {
        "last_tag": data.get("last_tag") if isinstance(data.get("last_tag"), dict) else None,
        "events": [item for item in data.get("events", []) if isinstance(item, dict)][:MAX_EVENTS],
    }
    temp_path = state_path.with_name(f".{state_path.name}.{os.getpid()}.tmp")
    temp_path.write_text(json.dumps(payload, indent=2, sort_keys=True) + "\n", encoding="utf-8")
    temp_path.replace(state_path)


def _empty_state() -> dict[str, Any]:
    return {"last_tag": None, "events": []}


def _event(
    event_type: str,
    message: str,
    *,
    uid: str | None = None,
    character_name: str | None = None,
    level: str = "info",
) -> dict[str, Any]:
    return {
        "type": event_type,
        "level": level,
        "message": message,
        "uid": uid,
        "character_name": character_name,
        "created_at": _now_iso(),
    }


def _now_iso() -> str:
    return datetime.now(timezone.utc).isoformat(timespec="seconds")

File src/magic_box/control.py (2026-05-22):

"""Small file-based controls shared by the admin UI and playback service."""

from __future__ import annotations

import json
import logging
import os
from pathlib import Path
import time
from typing import Any


LOGGER = logging.getLogger(__name__)
STOP_COMMAND = "stop"


def control_file_for_config(config_path: str | Path) -> Path:
    """Default to a control file beside characters.json."""

    return Path(config_path).expanduser().resolve().parent / "control.json"


def request_stop(control_path: str | Path) -> None:
    """Ask the running playback service to stop its current audio."""

    path = Path(control_path).expanduser().resolve()
    path.parent.mkdir(parents=True, exist_ok=True)
    payload = {"command": STOP_COMMAND, "requested_at": time.time()}
    temp_path = path.with_name(f".{path.name}.{os.getpid()}.tmp")
    temp_path.write_text(json.dumps(payload, sort_keys=True) + "\n", encoding="utf-8")
    temp_path.replace(path)


def consume_stop_request(control_path: str | Path) -> bool:
    """Return True once for a pending stop request, then remove it."""

    path = Path(control_path).expanduser().resolve()
    try:
        raw = path.read_text(encoding="utf-8")
    except FileNotFoundError:
        return False
    except OSError as exc:
        LOGGER.warning("Could not read control file %s: %s", path, exc)
        return False

    try:
        payload: Any = json.loads(raw)
    except json.JSONDecodeError:
        LOGGER.warning("Ignoring invalid control file %s", path)
        _unlink_control_file(path)
        return False

    _unlink_control_file(path)
    return isinstance(payload, dict) and str(payload.get("command", "")).strip().lower() == STOP_COMMAND


def _unlink_control_file(path: Path) -> None:
    try:
        path.unlink(missing_ok=True)
    except OSError as exc:
        LOGGER.warning("Could not remove control file %s: %s", path, exc)

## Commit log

2026-05-22 Initial open-source release
    [magic-character-box-case.scad, nfc-character-base-flat.stl, nfc-character-base.scad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]
2026-07-08 Ignore same-tag playback self-interrupts
2026-07-09 Skip idle remote audio stops
    [audio.py, test_audio.py]
2026-07-20 Fix player boot target ordering
    [test_systemd_audio.py]
2026-07-21 Add fixed-window Story Sticker locator playback
    [config.py, nfc.py, test_config.py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]
2026-07-22 Read Story Sticker shortcut in one NFC window
    [config.py, nfc.py, test_config.py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]
2026-07-22 Reconcile Story Sticker shortcut reader with founder dock
    [nfc.py, test_nfc_ndef.py]
2026-07-23 Resolve Story Sticker suffixes from page 19
    [app.py, config.py, nfc.py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]
2026-08-02 Hand recovery flow back to owner portal
2026-08-03 Keep GPIO runtime pipes outside release slots
2026-09-06 Show clear Wi-Fi handoff before switching networks
